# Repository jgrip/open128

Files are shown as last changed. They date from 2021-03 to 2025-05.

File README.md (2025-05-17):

## Migrated to codeberg <https://codeberg.org/jgrip/Open128>

View this project on [CADLAB.io](https://cadlab.io/project/24751). 

# open128

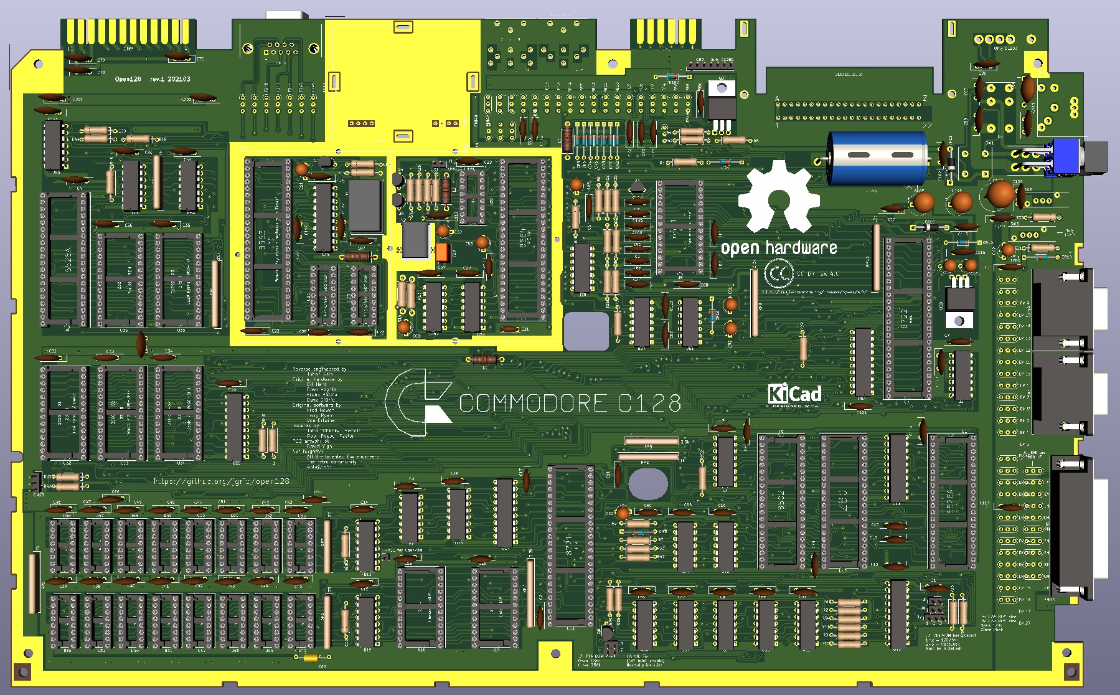
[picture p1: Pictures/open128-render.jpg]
Render of PCB


This is a clone of the Commodore 128 home computer made with KiCad, licensed under [CC BY-SA 4.0](https://creativecommons.org/licenses/by-sa/4.0/).

It contains both schematic and PCB layout, based on the Neo128 project by me.
This PCB has not yet been manufactured and tested however there are minimal changes compared to the well tested Neo128.

Some of the components have been copied from the [bit-preserve project](https://github.com/baldengineer/bit-preserve) and modified.

For Bill of Material and other documentation, please see https://c128.se

-----
This work is licensed under a
[Creative Commons Attribution-ShareAlike 4.0 International License][cc-by-sa].

[][cc-by-sa]

[cc-by-sa]: http://creativecommons.org/licenses/by-sa/4.0/
[cc-by-sa-image]: https://licensebuttons.net/l/by-sa/4.0/88x31.png
[cc-by-sa-shield]: https://img.shields.io/badge/License-CC%20BY--SA%204.0-lightgrey.svg

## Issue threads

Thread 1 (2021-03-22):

Silkscreen issues

jgrip, 2021-03-22:
The silk screen is a bit messed up and needs to be fixed.

Component values, most of the EMI references etc.

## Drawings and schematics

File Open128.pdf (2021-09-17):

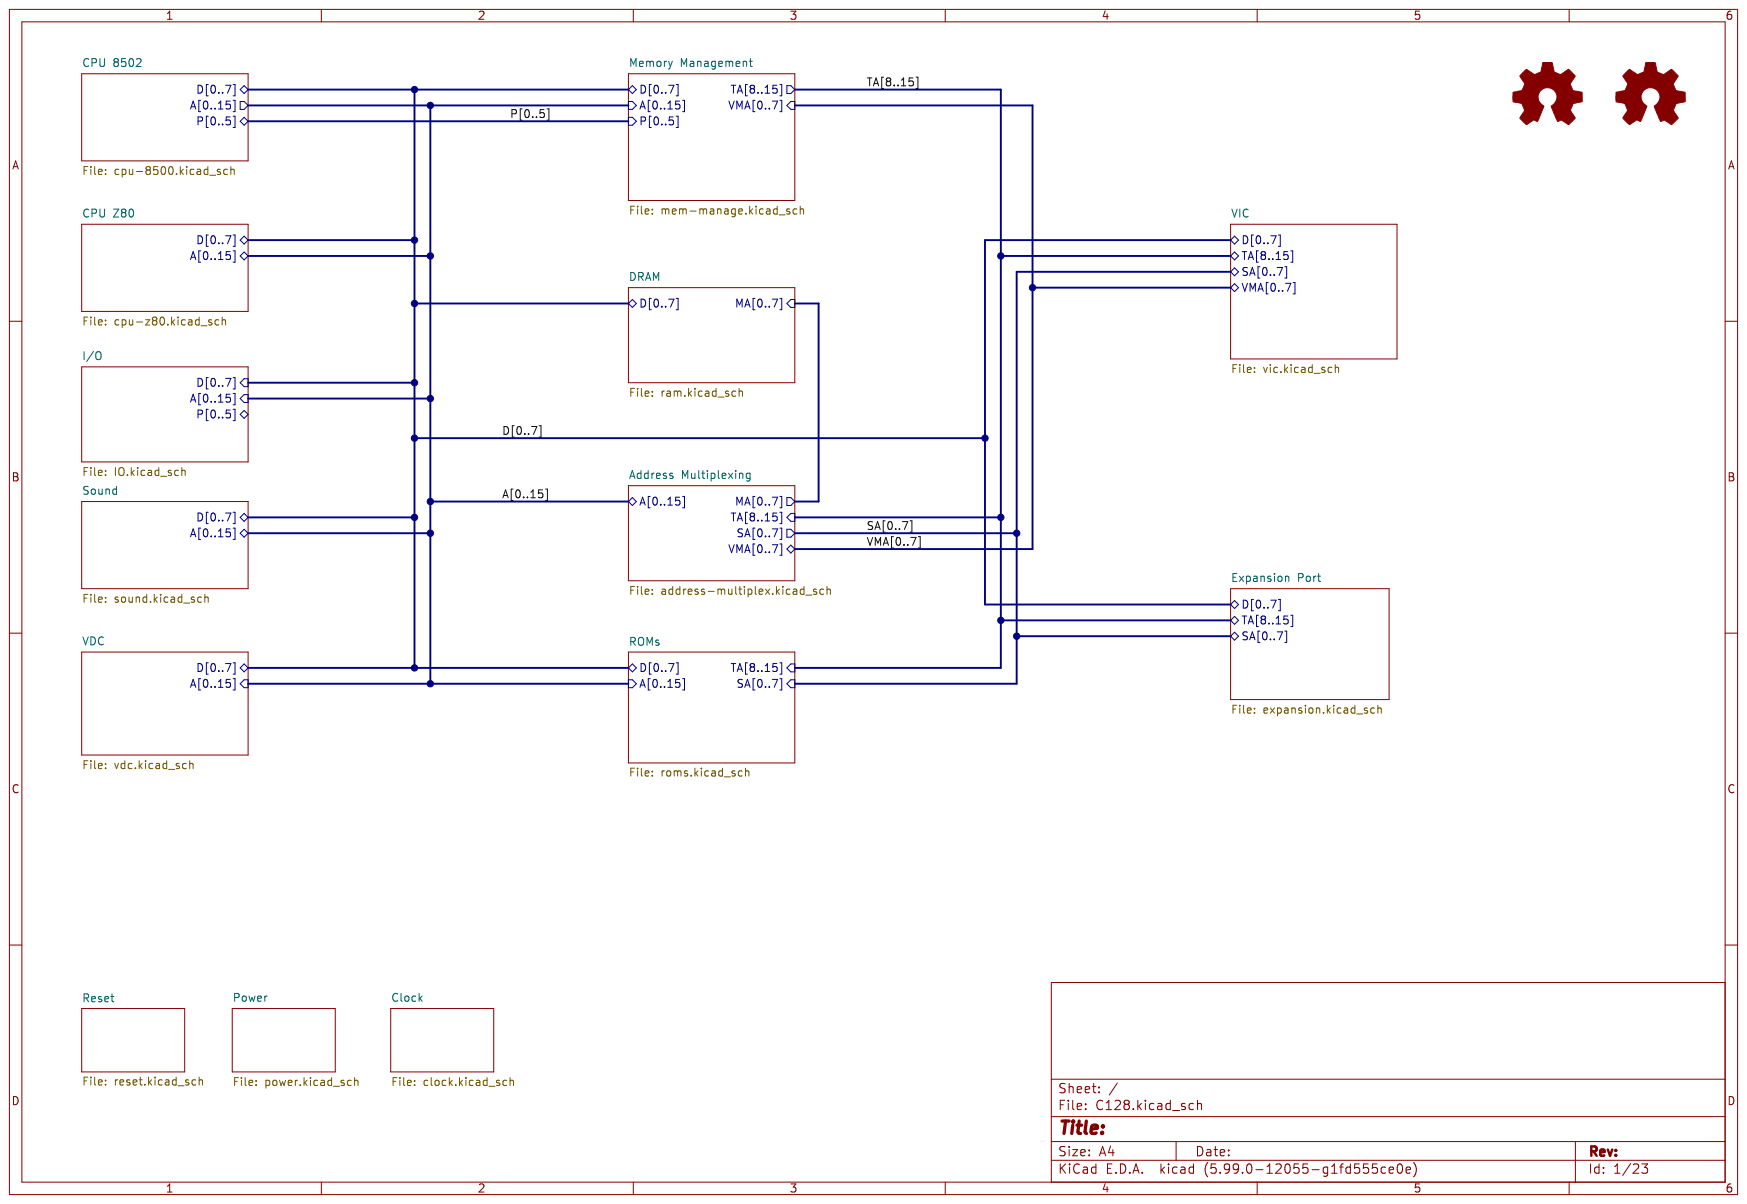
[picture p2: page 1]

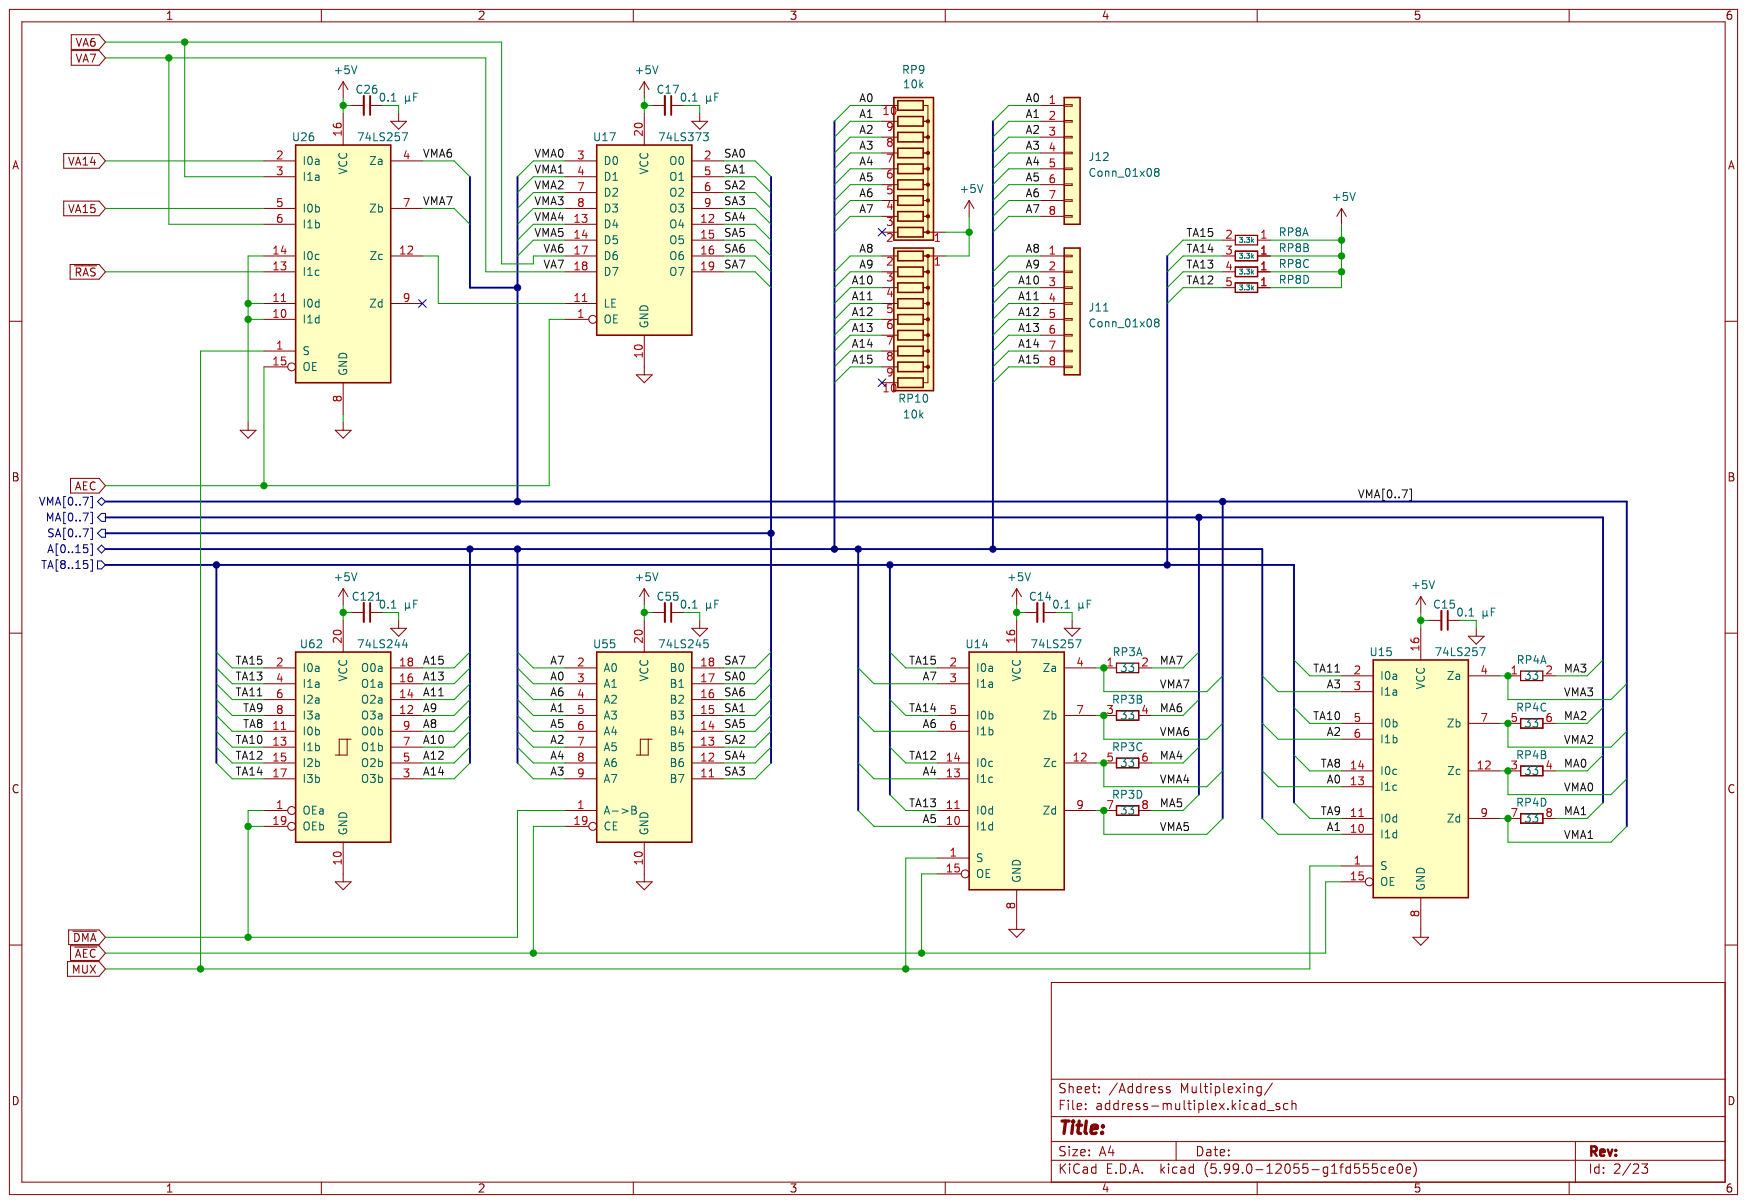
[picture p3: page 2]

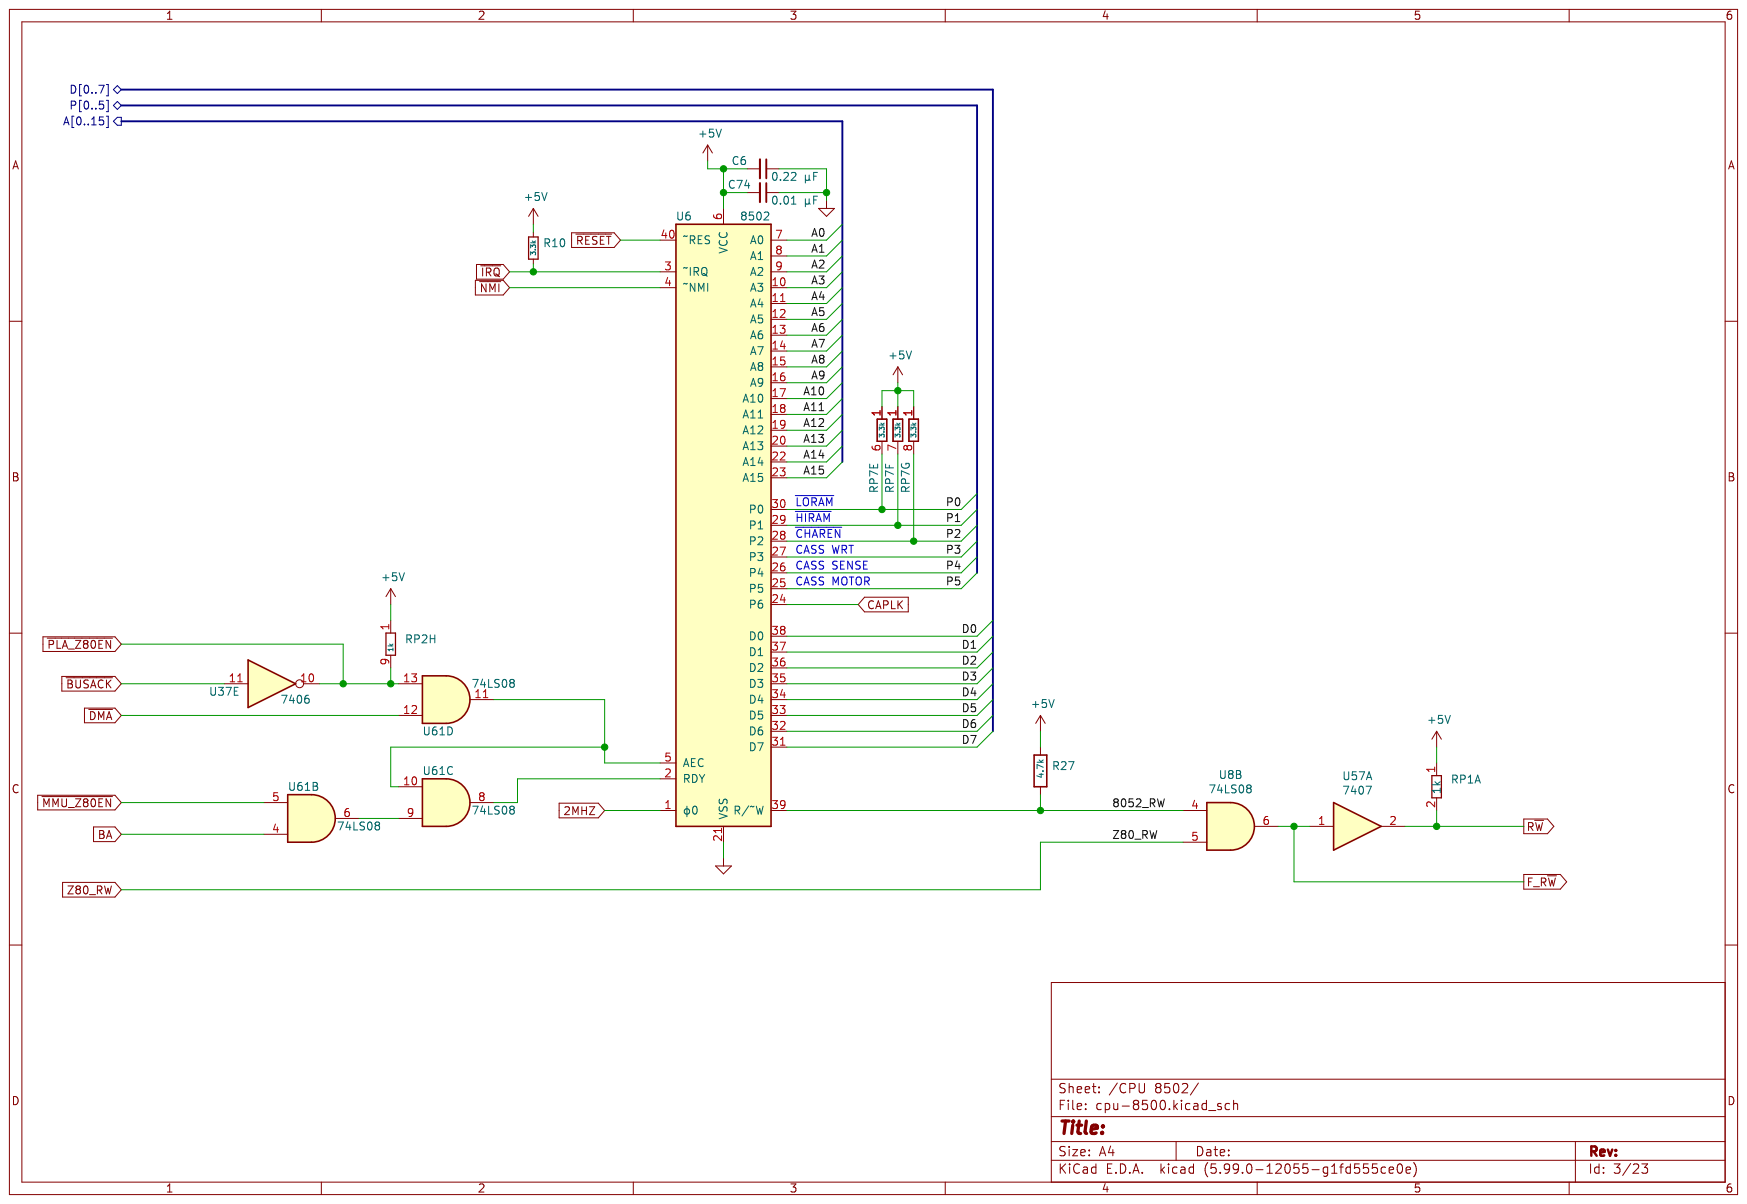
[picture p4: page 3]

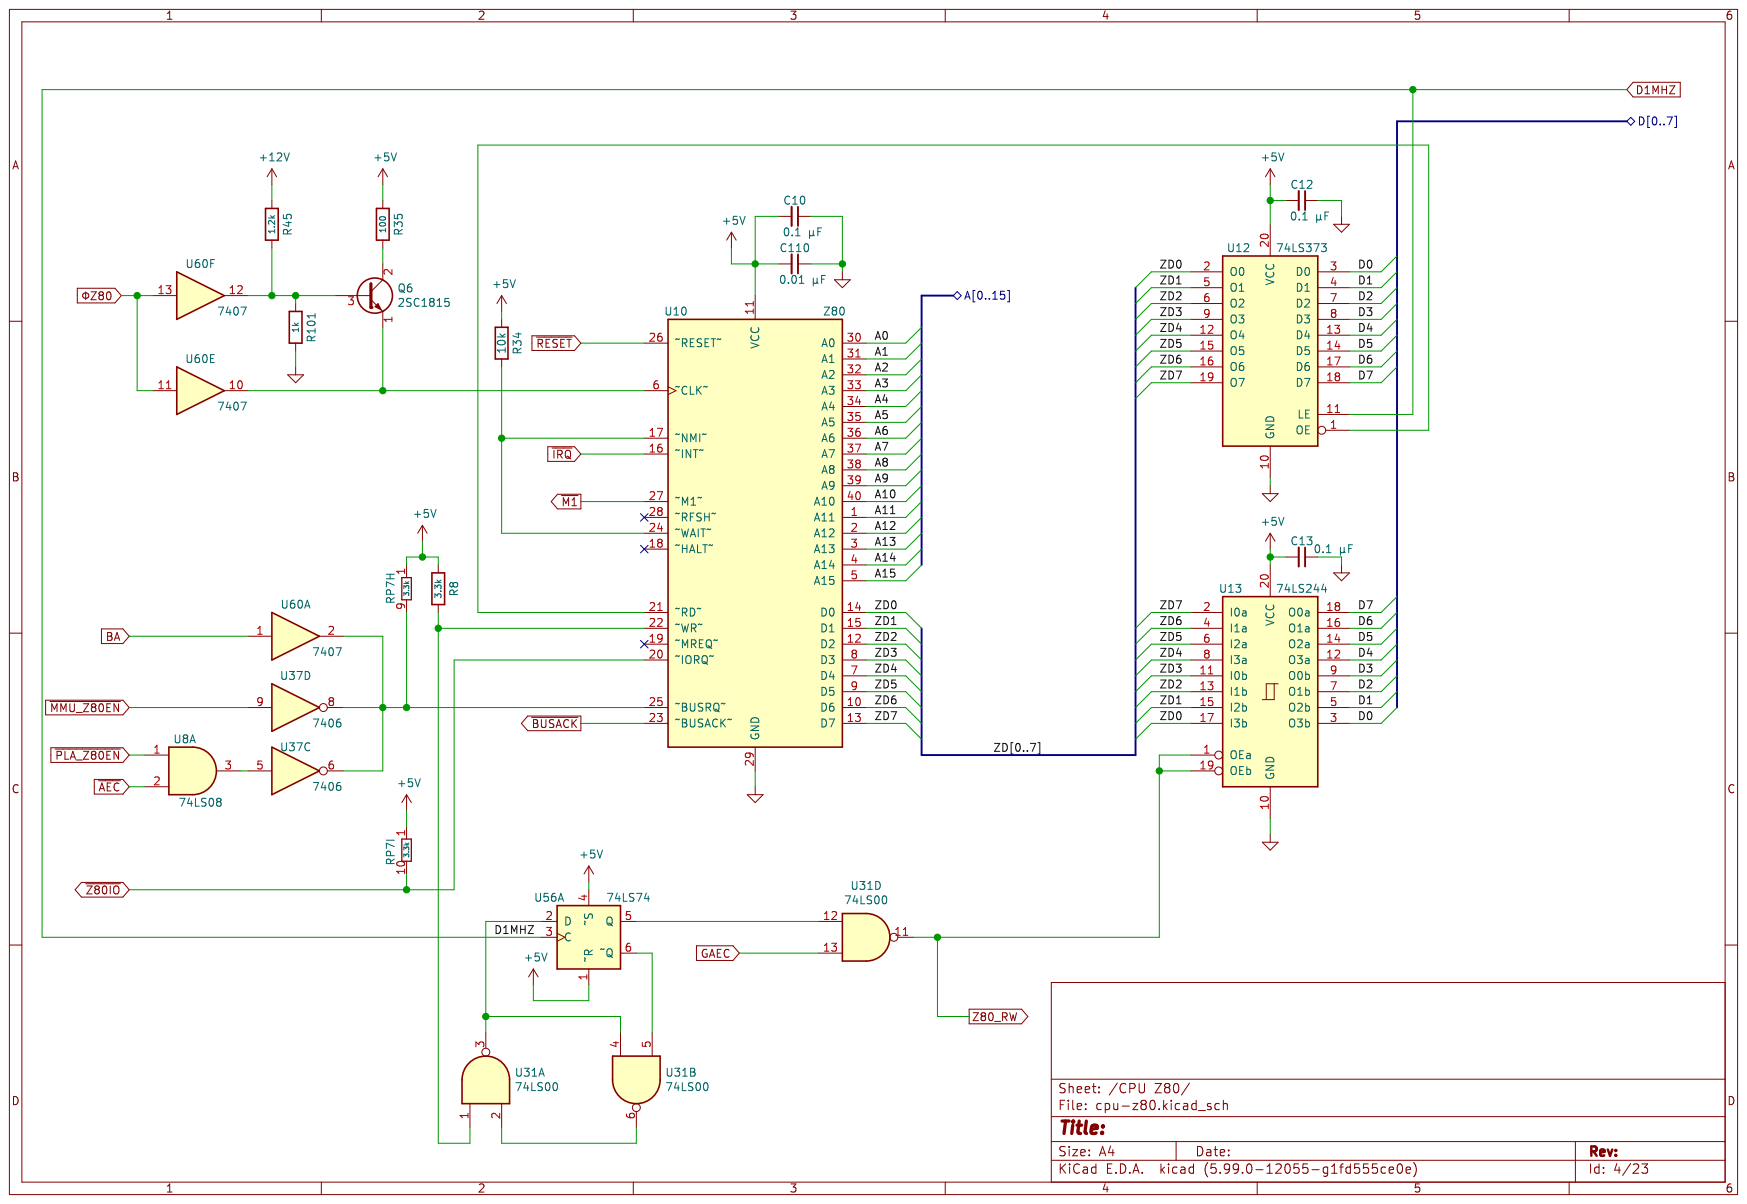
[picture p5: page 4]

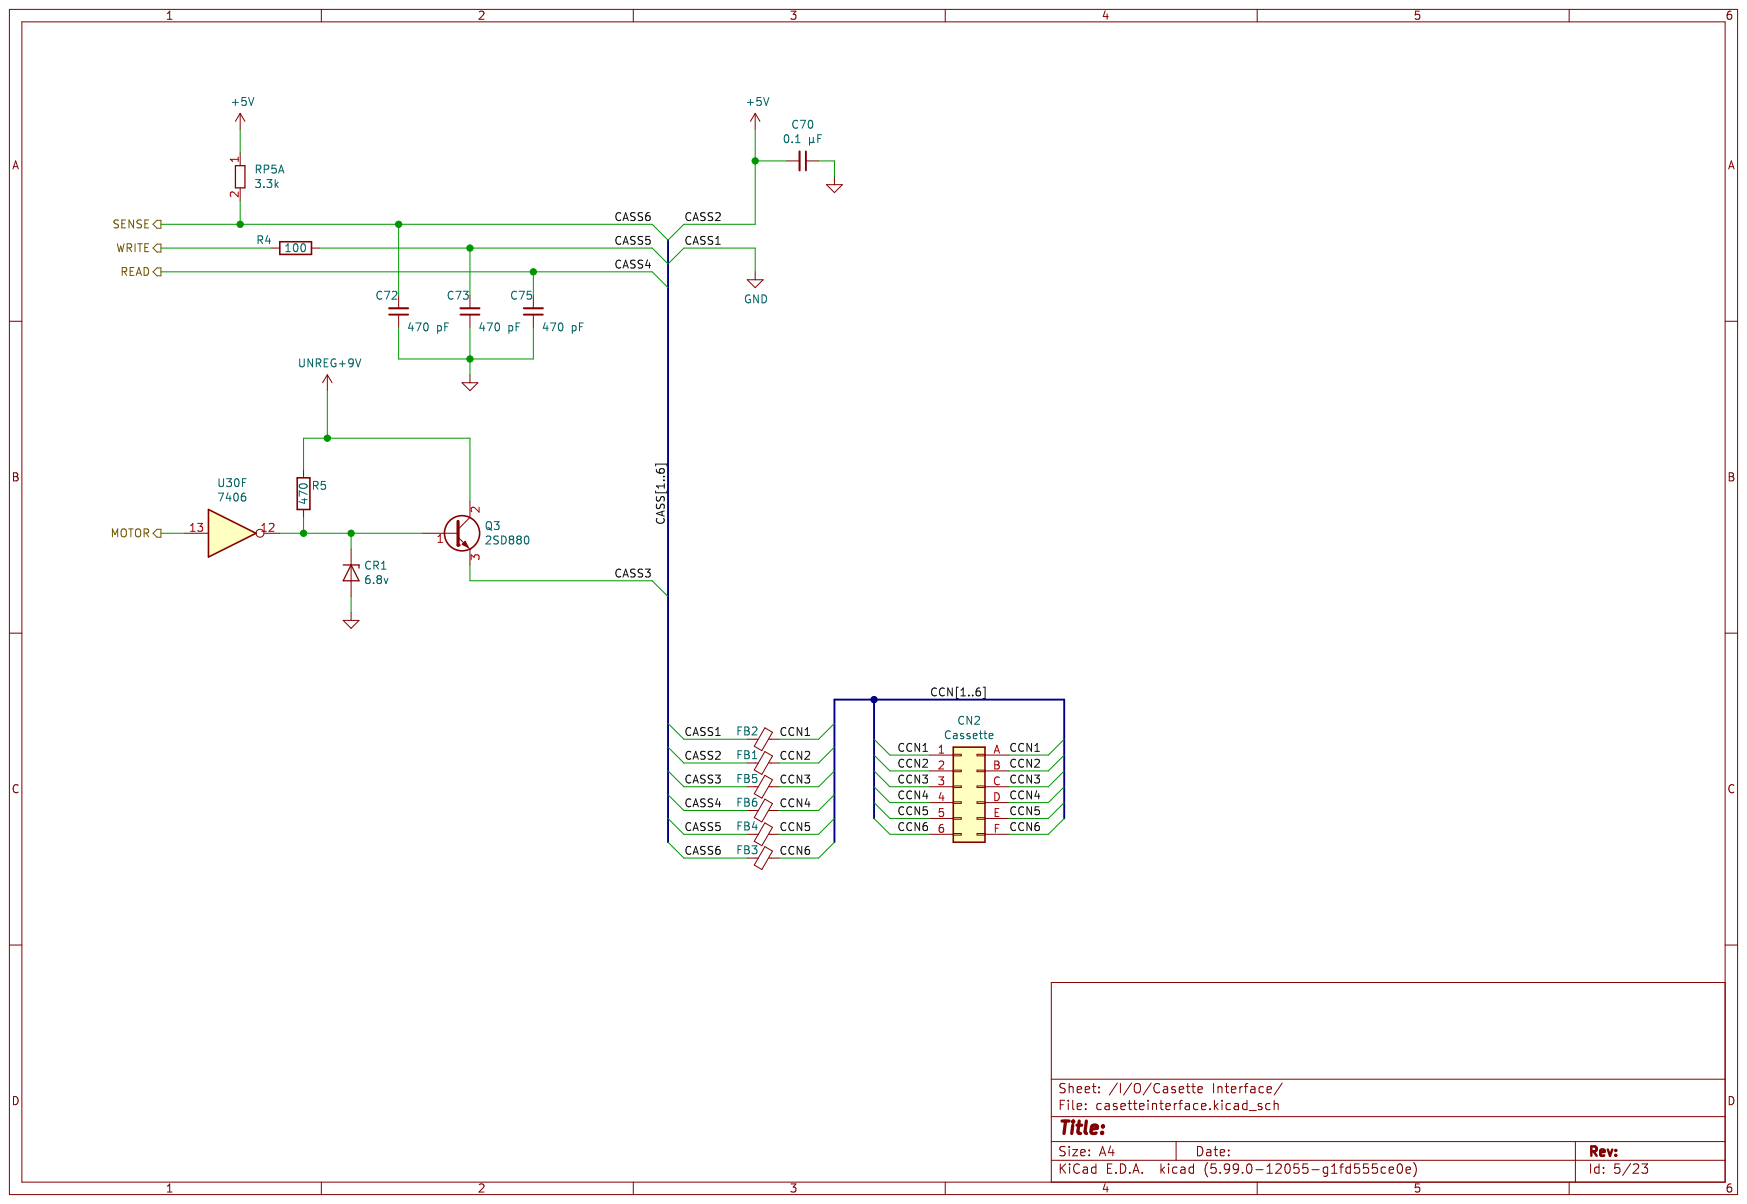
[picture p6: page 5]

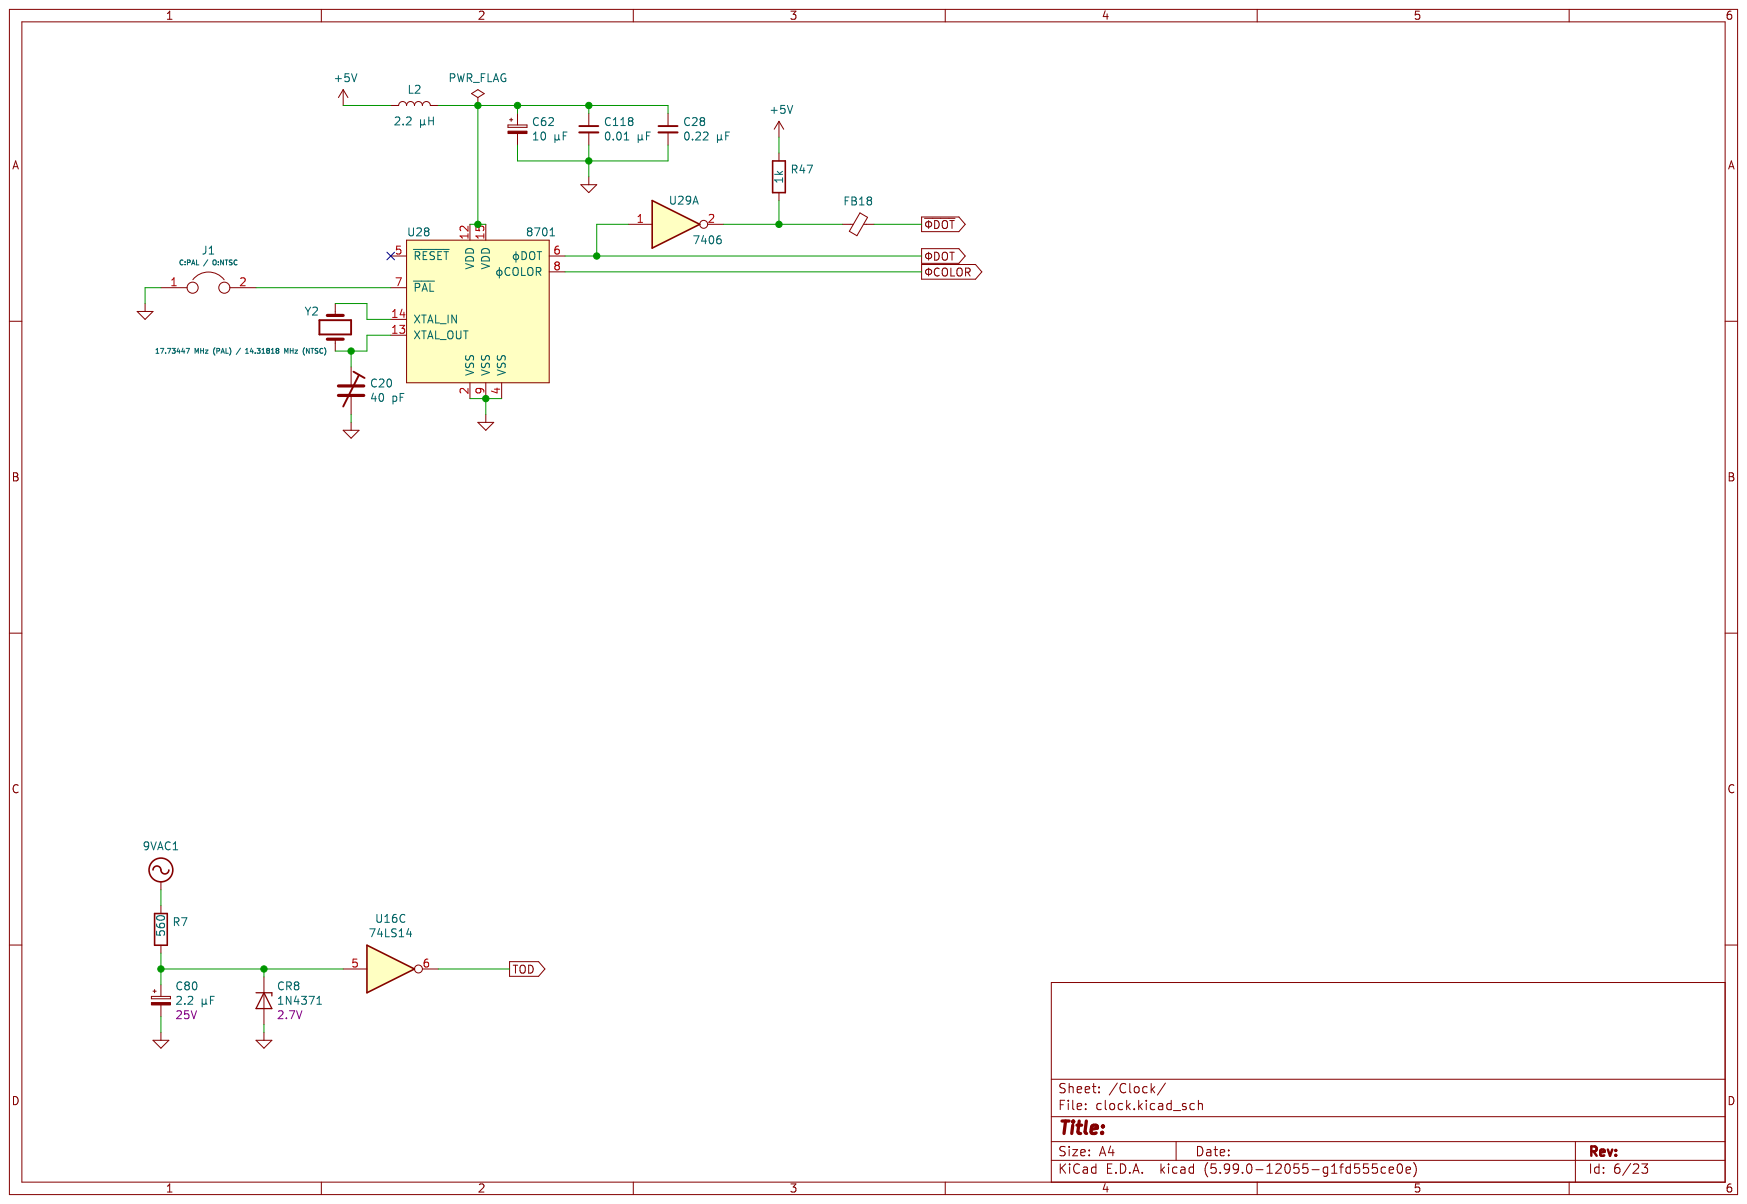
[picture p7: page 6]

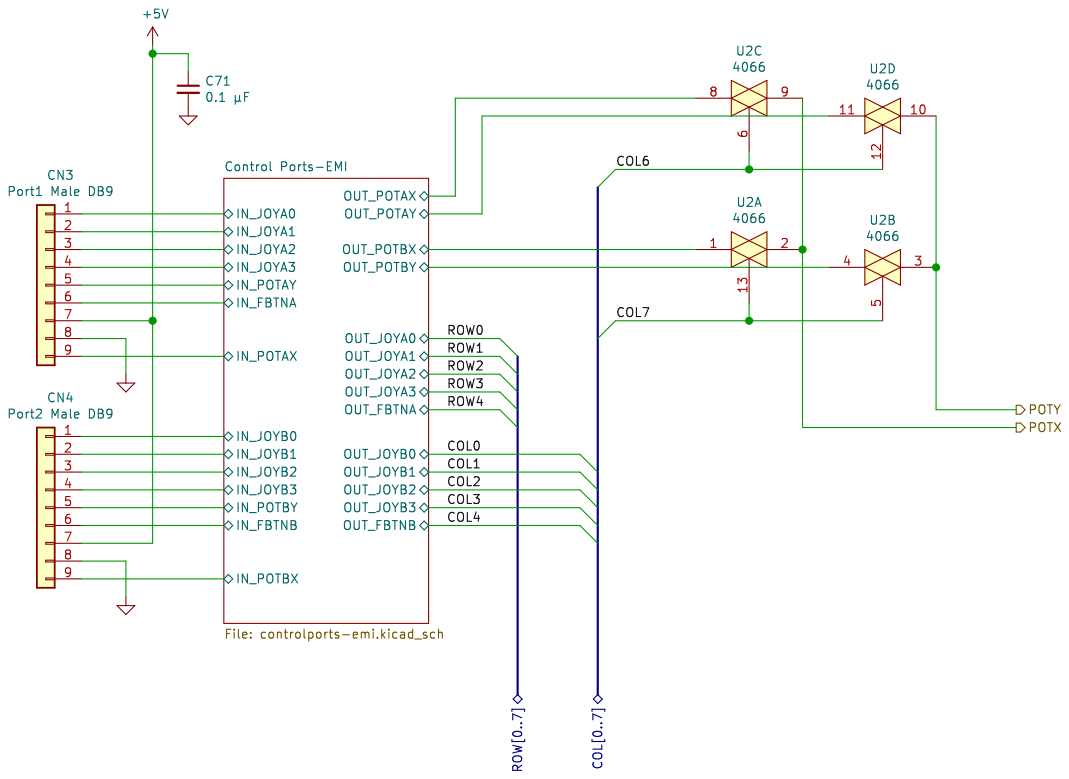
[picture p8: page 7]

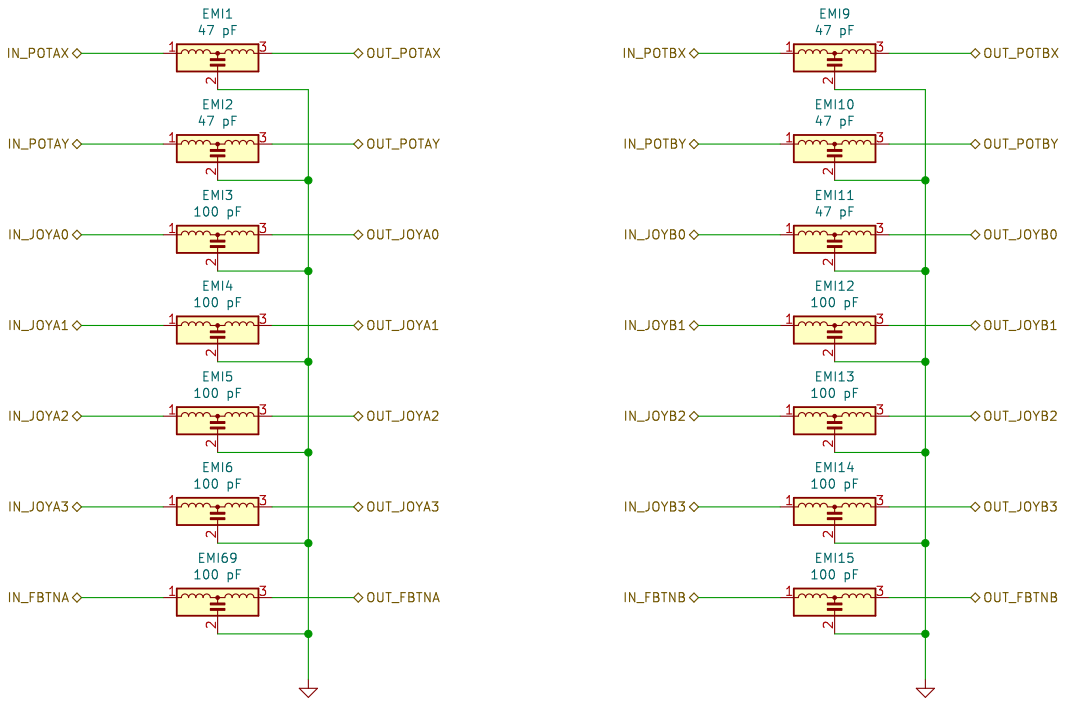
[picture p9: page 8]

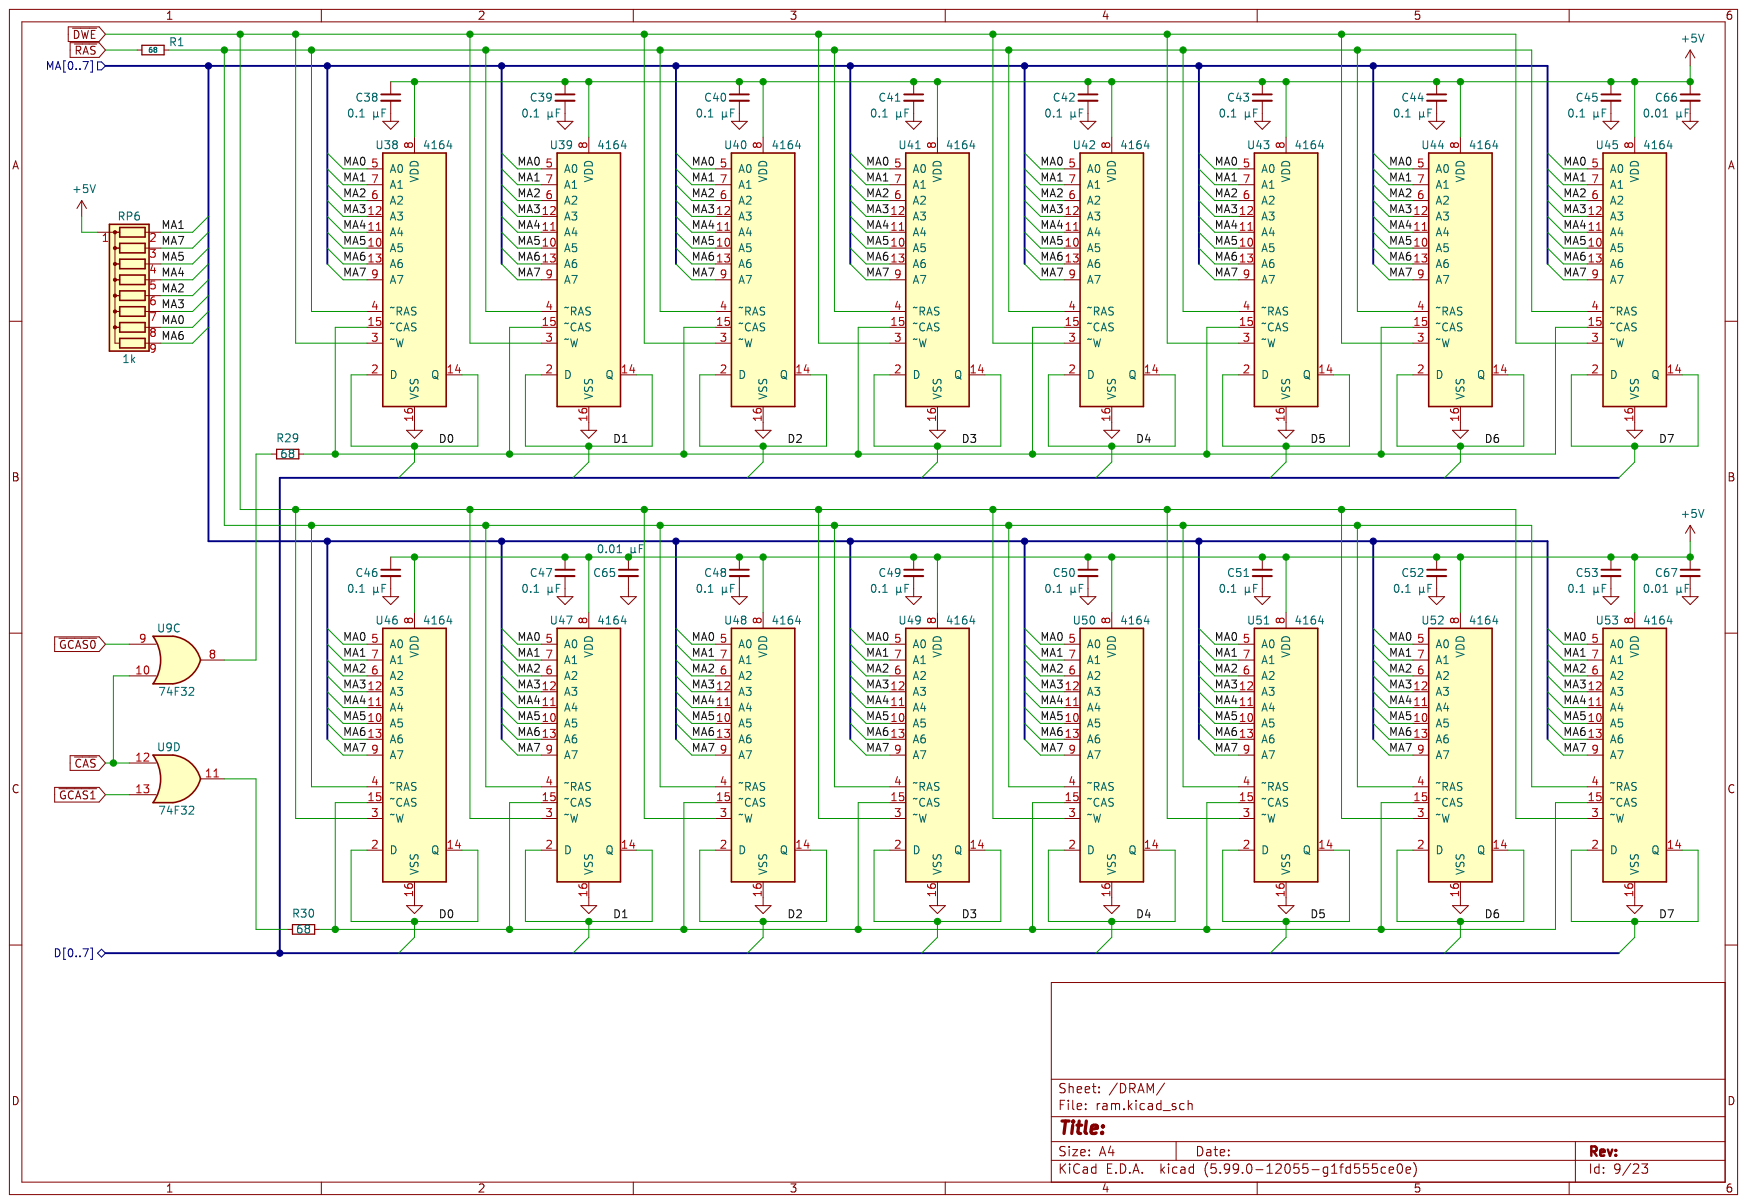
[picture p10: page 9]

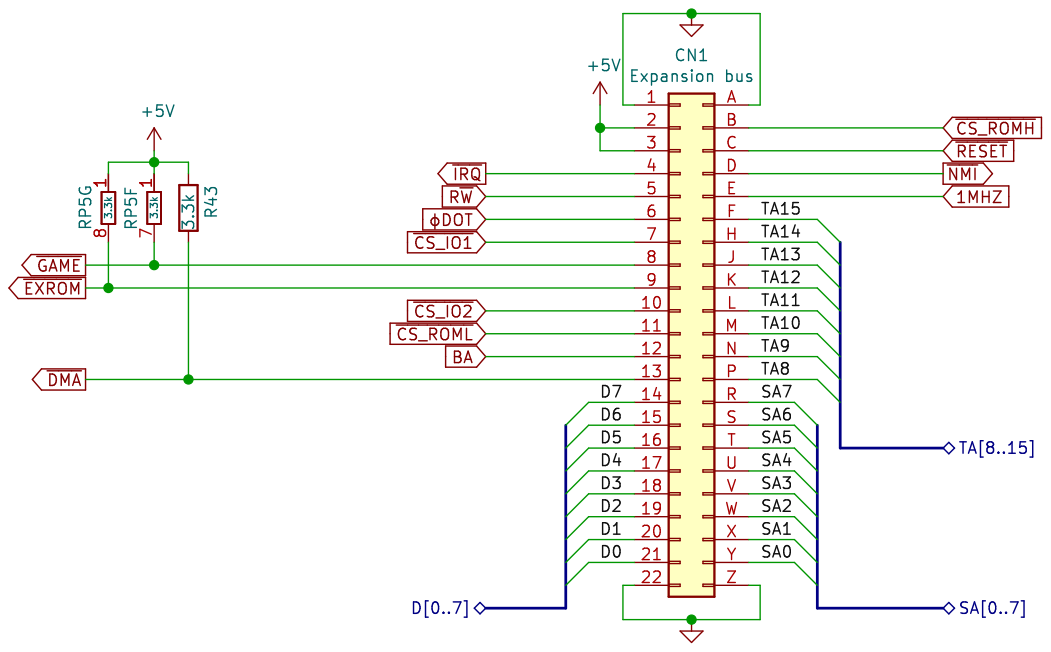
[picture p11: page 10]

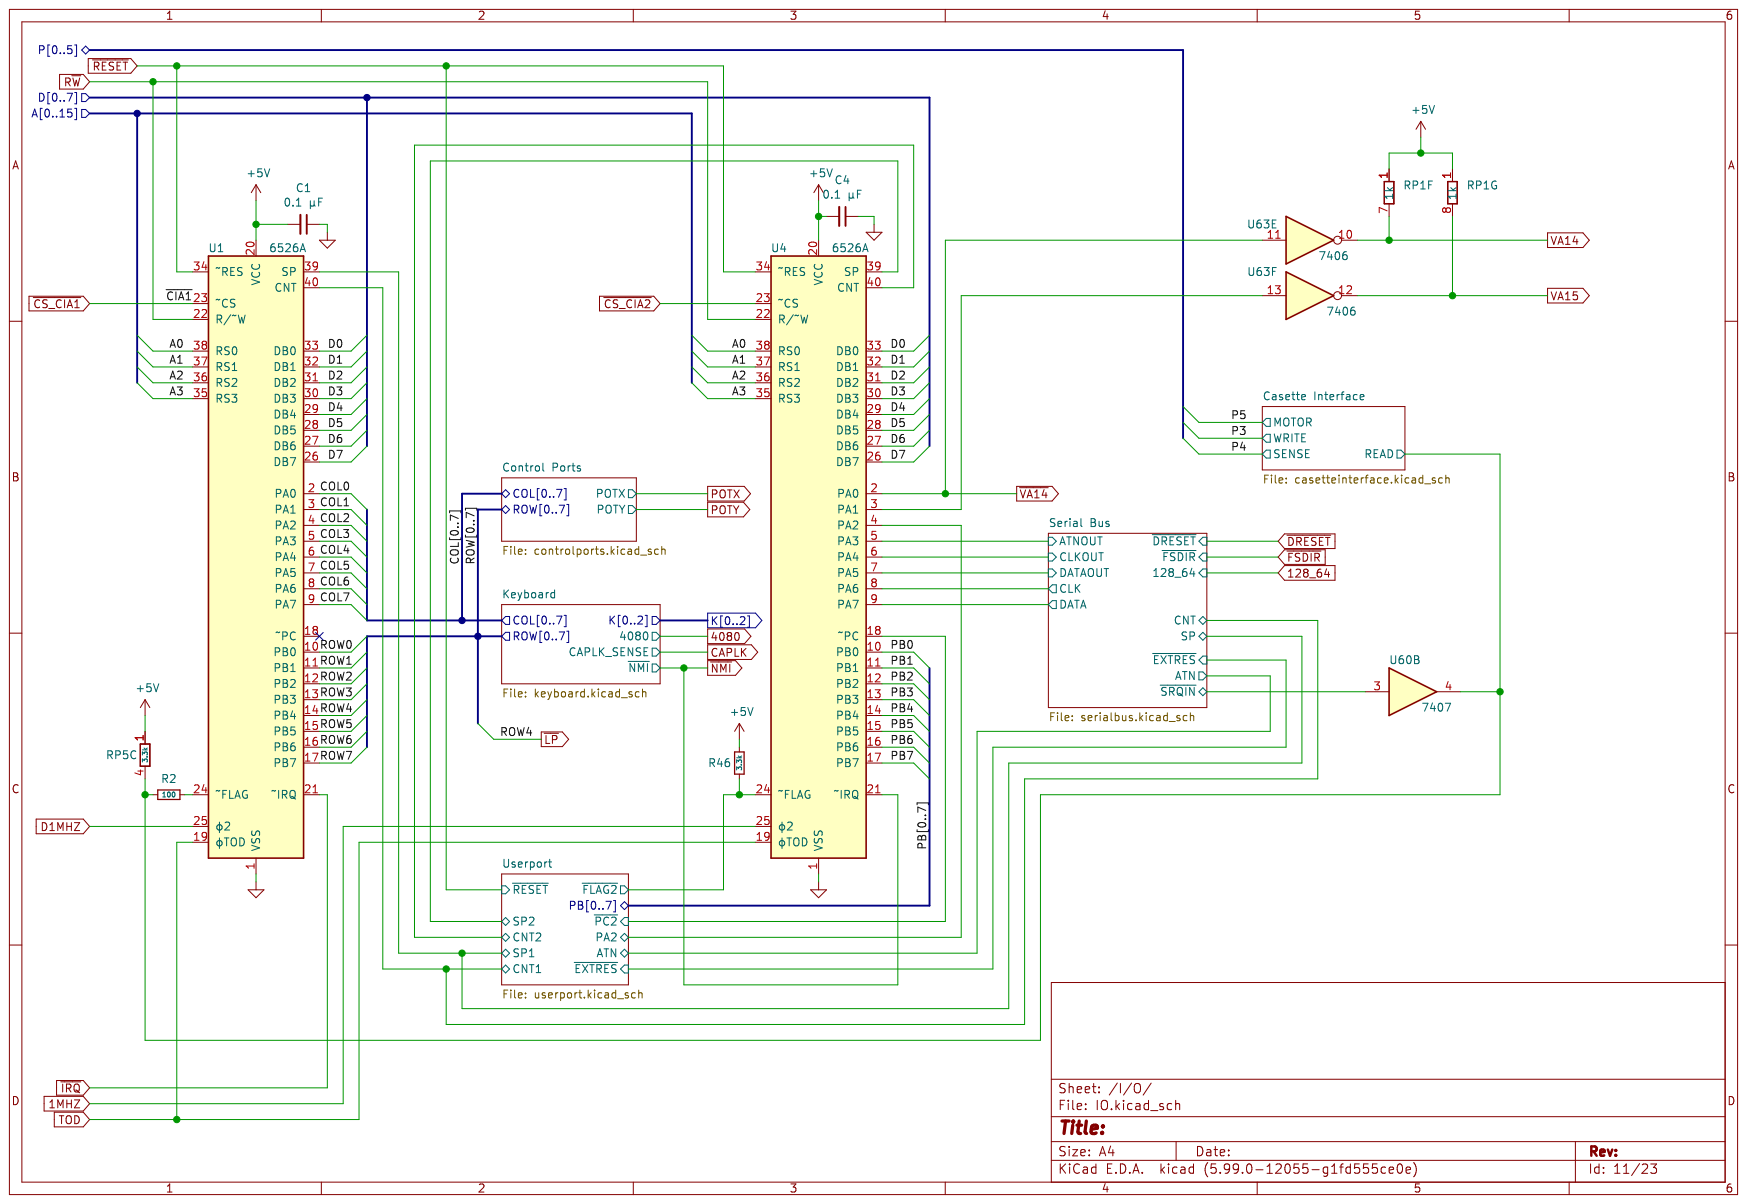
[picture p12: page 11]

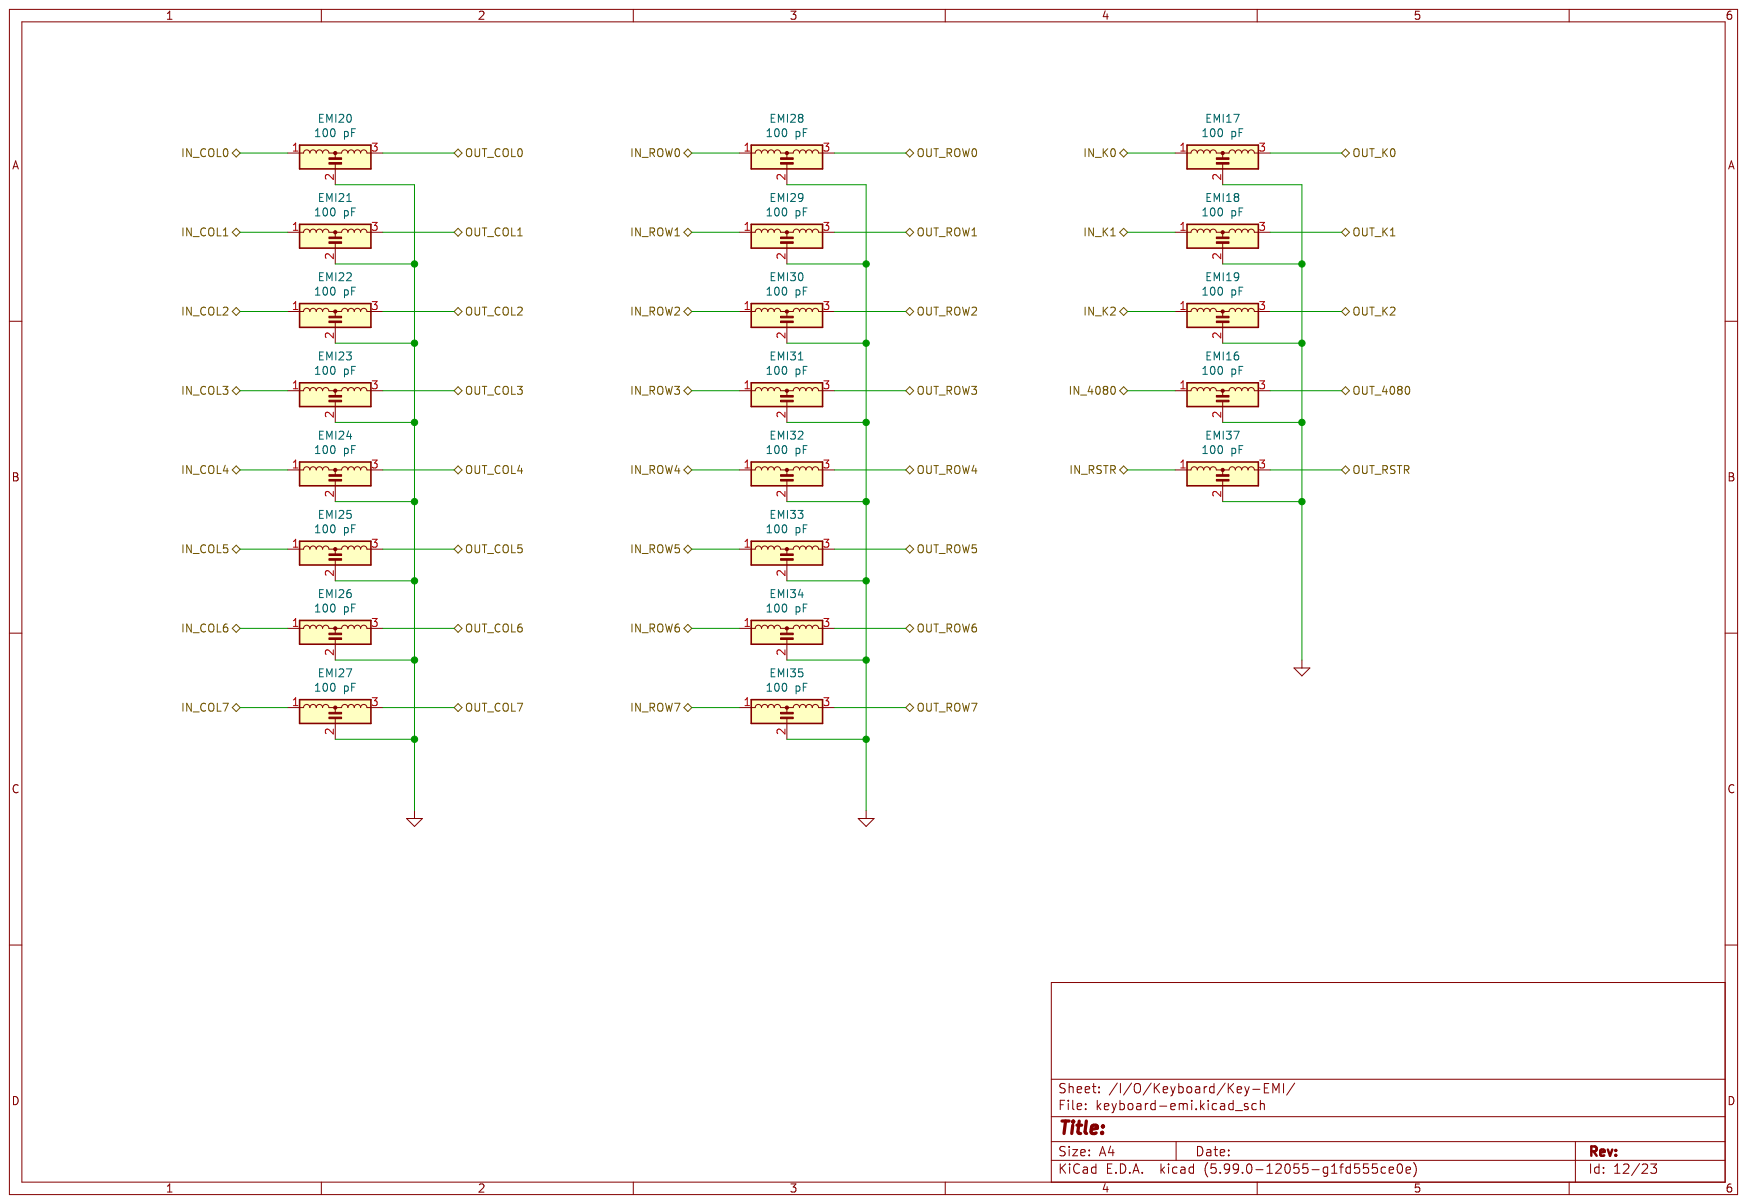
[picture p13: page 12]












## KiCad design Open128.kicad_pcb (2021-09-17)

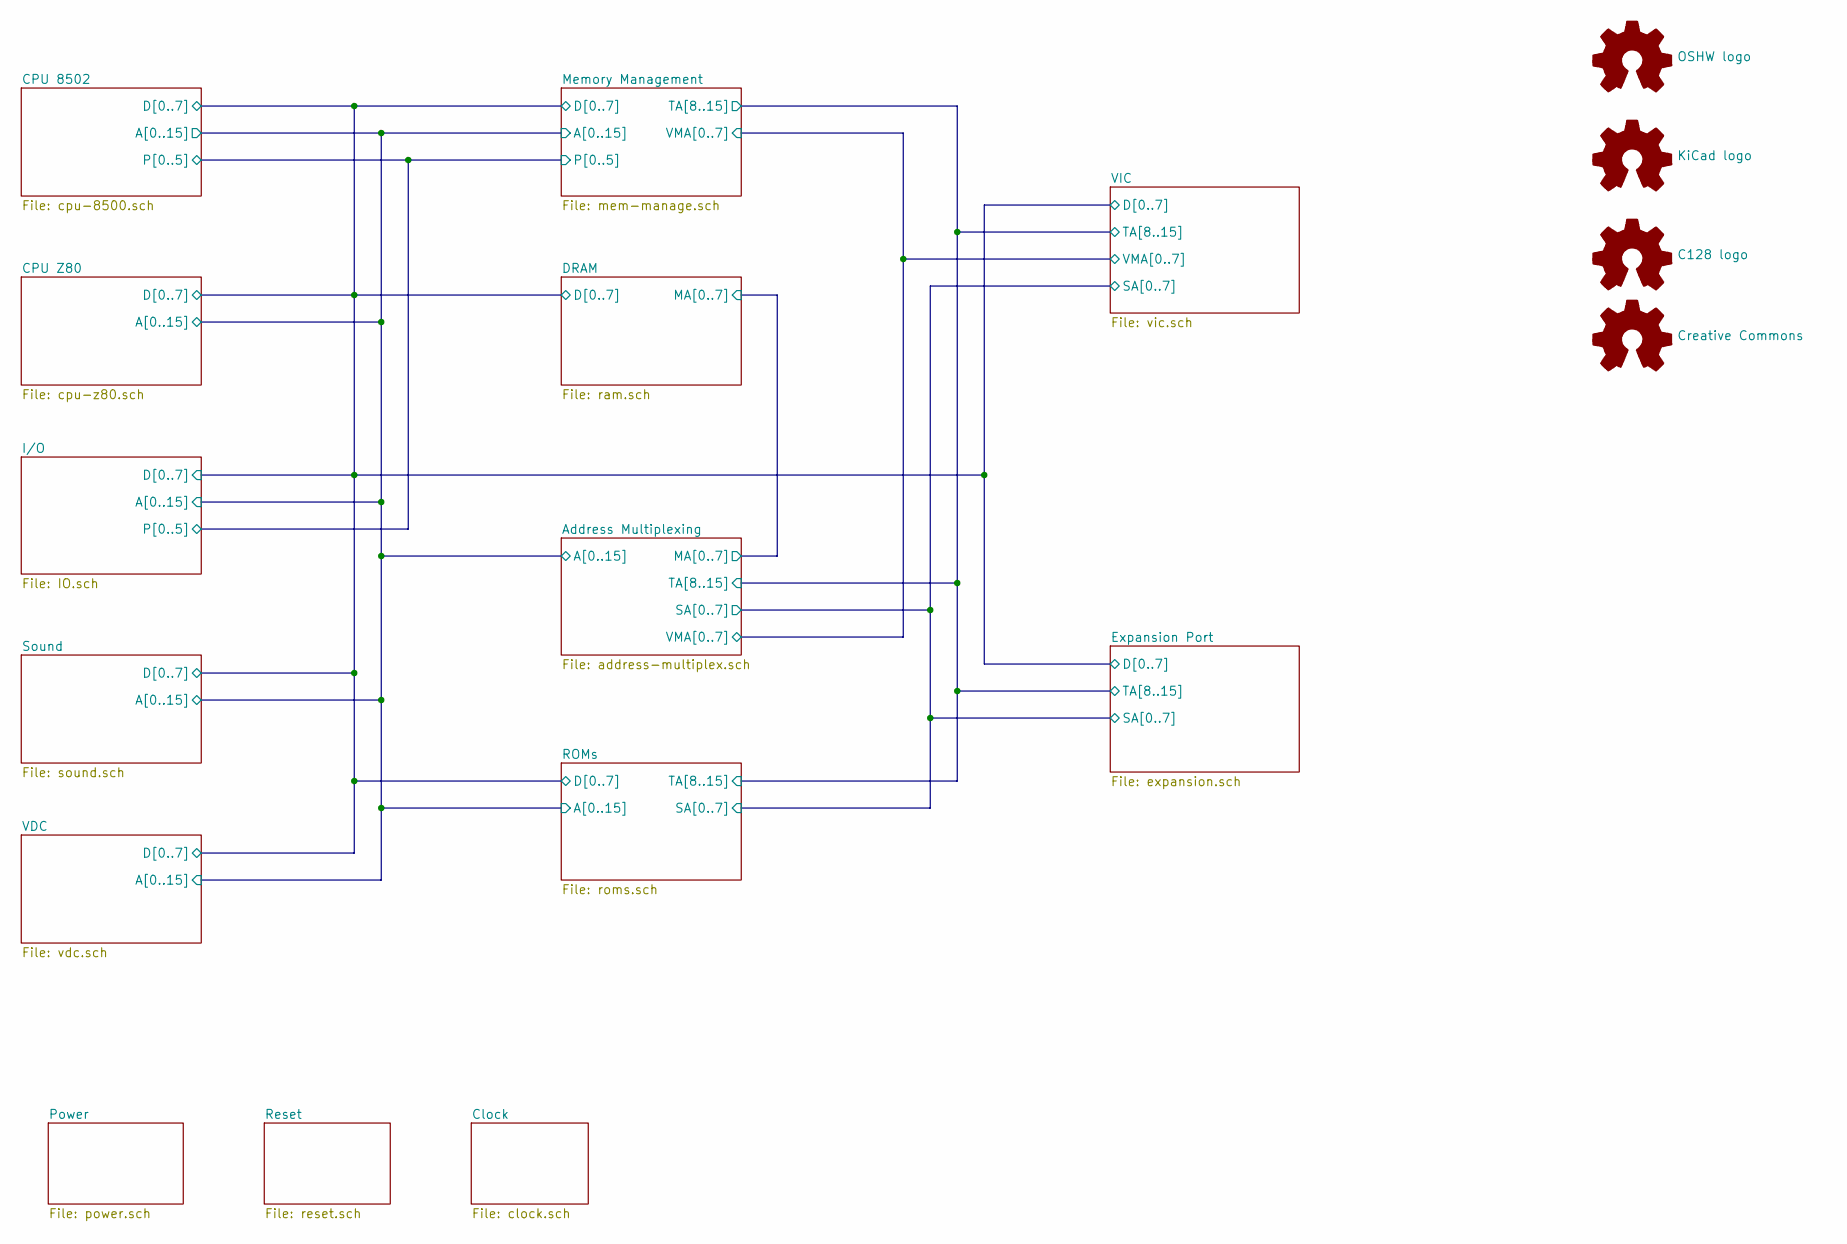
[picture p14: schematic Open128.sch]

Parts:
LOGO1: OSHW logo; OSHW-Logo2_48.7x40mm_SilkScreen
LOGO2: KiCad logo; KiCad-Logo2_8mm_SilkScreen
LOGO3: C128 logo; C128-logo
LOGO4: Creative Commons; Symbol_CreativeCommons_SilkScreenTop_Type2_Big

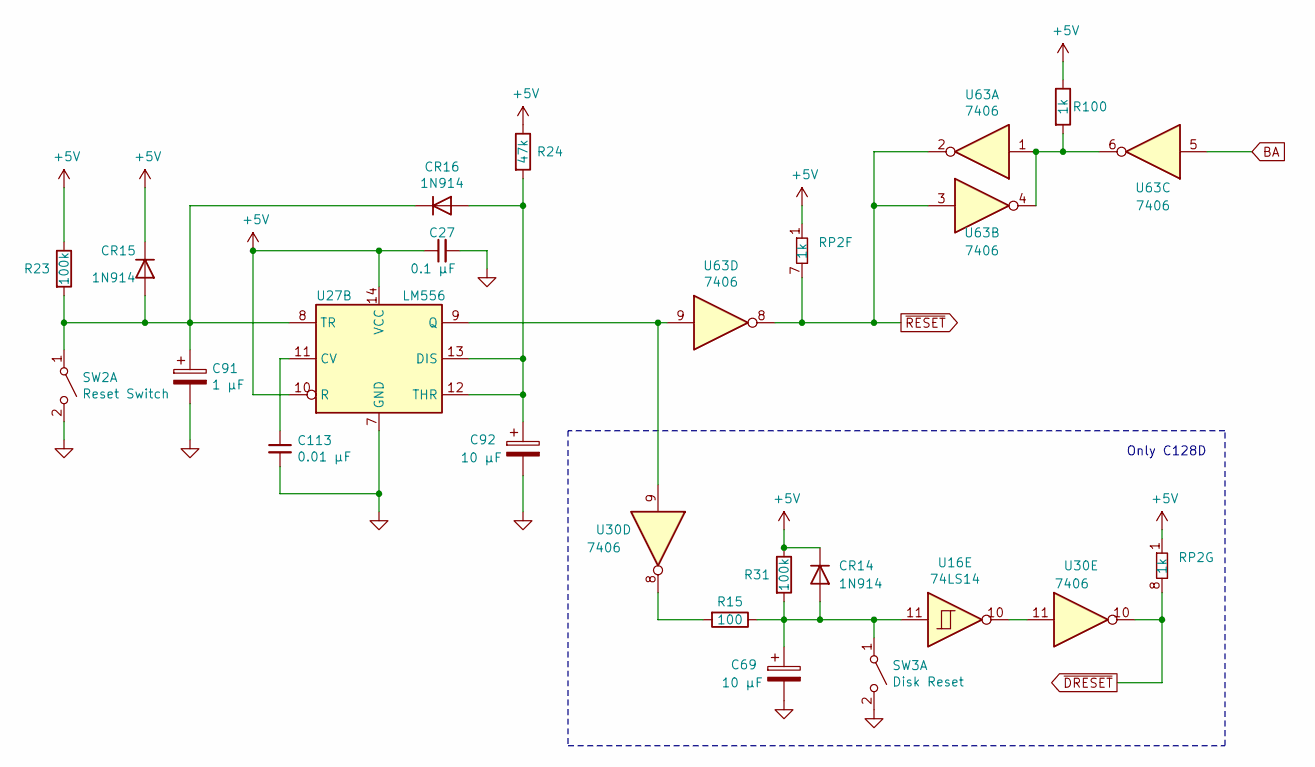
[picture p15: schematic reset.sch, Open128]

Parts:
C27: 0.1 µF; C_Disc_D10.0mm_W2.5mm_P5.00mm; Voltage Rating 25V; Voltage Tolerance +80% -20%; Mouser Part 581-SA105E104MAR
C69, C92: 10 µF; CP_Radial_Tantal_D5.0mm_P5.00mm; Voltage Rating 16V; Mouser Part 647-UVR1H100MDD1TD
C91: 1 µF; CP_Radial_Tantal_D5.0mm_P5.00mm; Voltage Rating 16V; Mouser Part 647-USA1H010MDD1TE
C113: 0.01 µF; C_Disc_D10.0mm_W2.5mm_P5.00mm; Voltage Rating 25V; Voltage Tolerance +80% -20%; Mouser Part 581-SA105E103M
CR14, CR15, CR16: 1N914; D_DO-35_SOD27_P12.70mm_Horizontal; Mouser Part 512-1N914
R15: 100; R_Axial_DIN0309_L9.0mm_D2.5mm_P12.70mm_Horizontal; Mouser Part 660-MF1/4DCT52A1000F
R23, R31: 100k; R_Axial_DIN0309_L9.0mm_D2.5mm_P12.70mm_Horizontal; Mouser Part 660-MF1/4LCT52R104J
R24: 47k; R_Axial_DIN0309_L9.0mm_D2.5mm_P12.70mm_Horizontal; Mouser Part 660-MF1/4LCT52R473J
R100: 1k; R_Axial_DIN0309_L9.0mm_D2.5mm_P12.70mm_Horizontal; Mouser Part 660-MF1/4LCT52R102J
RP2: 1k; R_Array_SIP9; Mouser Part 652-4609X-1LF-1K
SW2: Reset Switch; Switch-Pushbutton
SW3: Disk Reset; Switch-Pushbutton
U16: 74LS14; DIP-14_W7.62mm; Mouser Part 595-SN74LS14N
U27: LM556; DIP-14_W7.62mm; Mouser Part 595-NA556N
U30, U63: 7406; DIP-14_W7.62mm; Mouser Part 595-SN74LS06N

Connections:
+5V: C27.1, CR14.1 (K), CR15.1 (K), R23.1, R24.1, R31.1, R100.1, RP2.1 (common), U27.10 (R), U27.14 (VCC); also elsewhere on the board
BA: U63.5; also elsewhere on the board
GND: C27.2, C69.2, C91.2, C92.2, C113.2, SW2.2 (B), SW3.2 (B), U27.7 (GND); also elsewhere on the board
unnamed: C69.1, CR14.2 (A), R15.1, R31.2, SW3.1 (A), U16.11
unnamed: C91.1, CR15.2 (A), CR16.1 (K), R23.2, SW2.1 (A), U27.8 (TR)
unnamed: C92.1, CR16.2 (A), R24.2, U27.12 (THR), U27.13 (DIS)
unnamed: C113.1, U27.11 (CV)
unnamed: R15.2, U30.8
unnamed: R100.2, U63.1, U63.4, U63.6
unnamed: U16.10, U30.11
unnamed: U27.9 (Q), U30.9, U63.9
~DRESET: RP2.8 (R8), U30.10; also elsewhere on the board
~RESET: RP2.7 (R8), U63.2, U63.3, U63.8; also elsewhere on the board

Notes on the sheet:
Only C128D

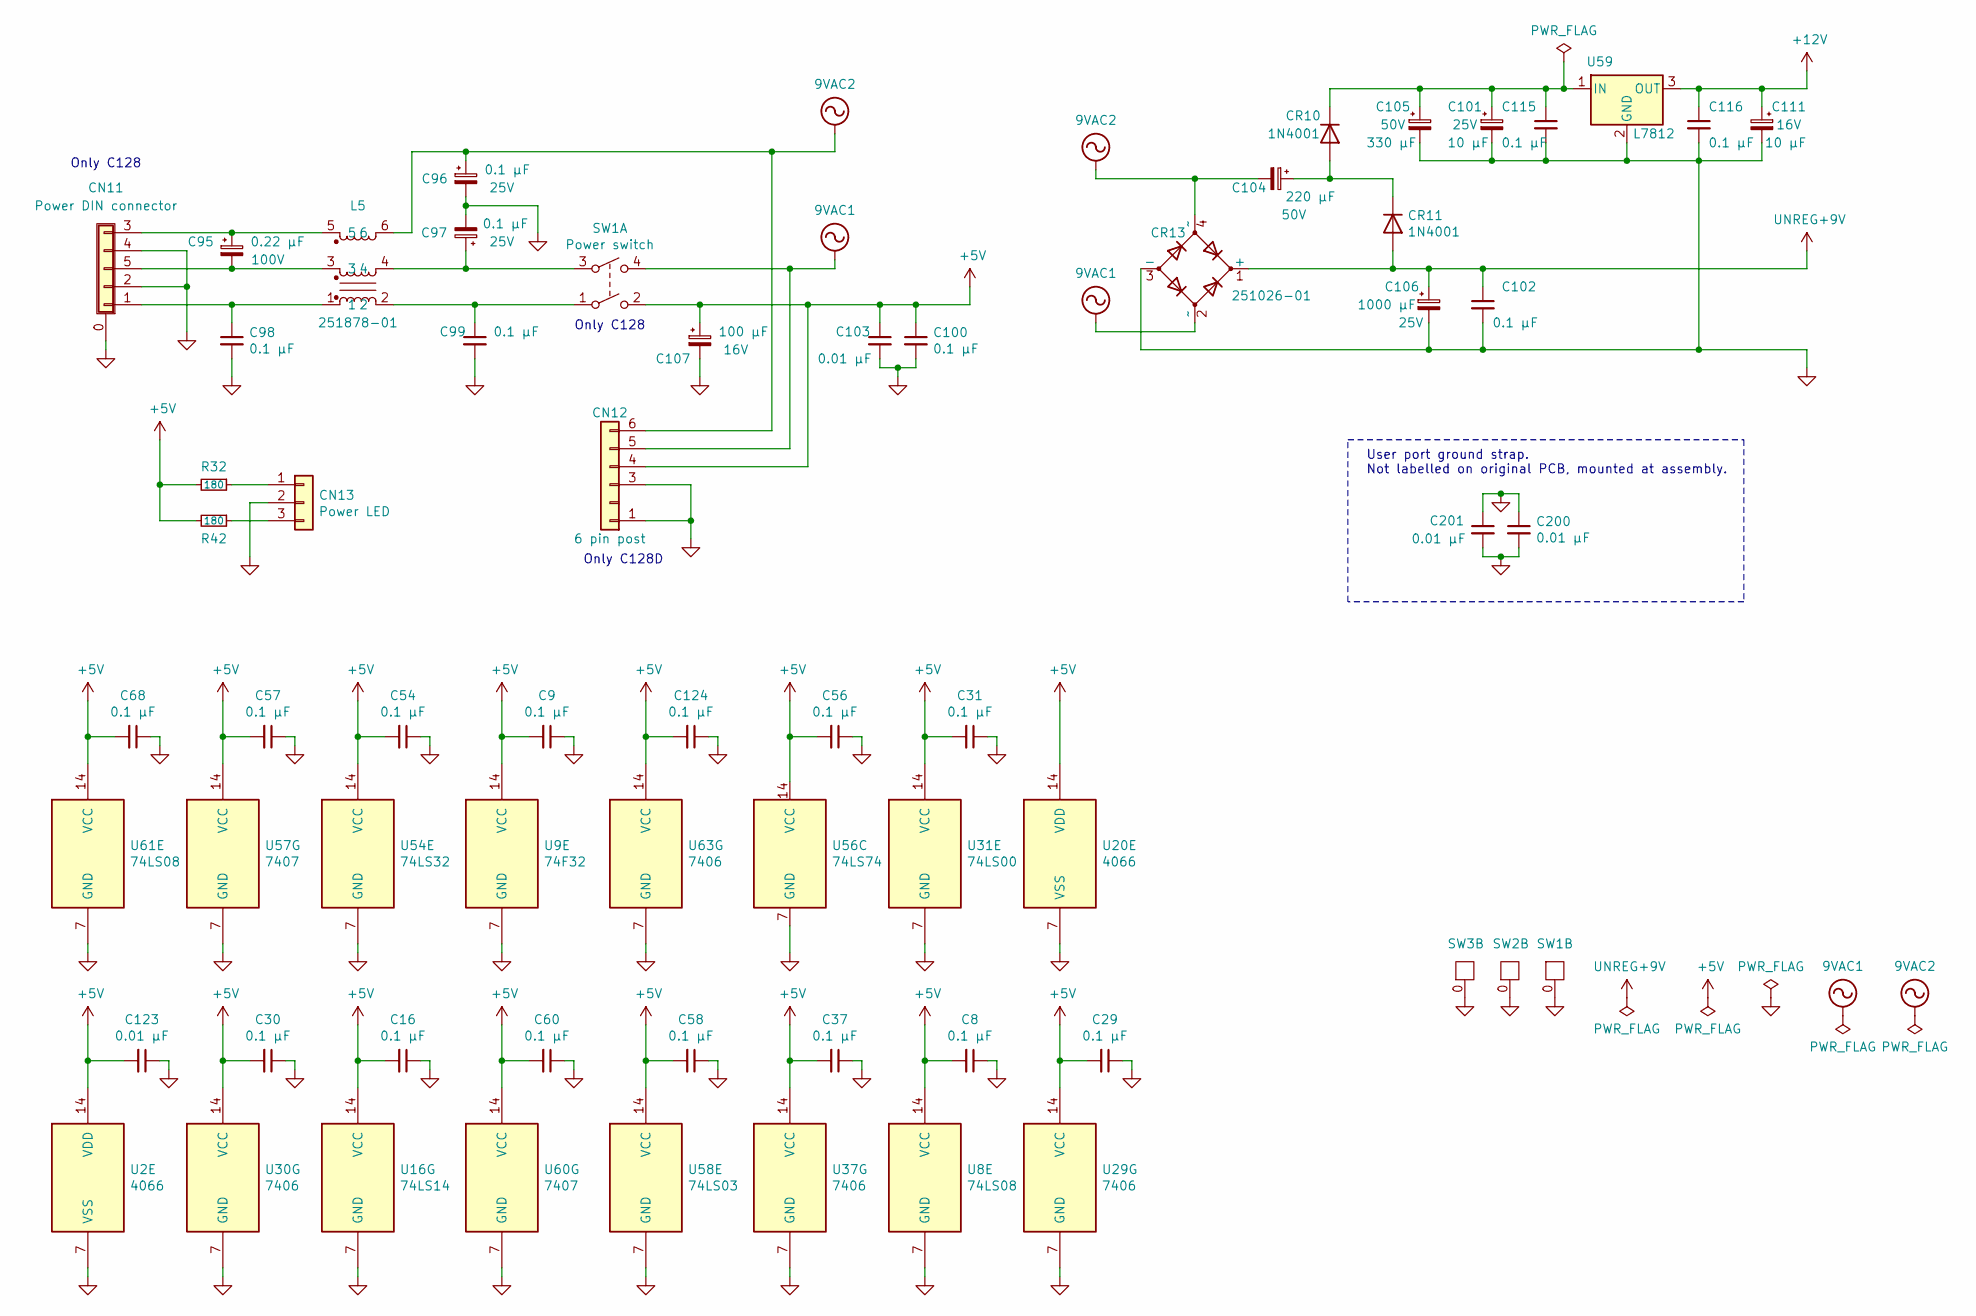
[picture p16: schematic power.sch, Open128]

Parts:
C8, C9, C16, C29, C30, C31, C37, C54, C56, C57, C58, C60, C68, C96, C97, C98, C99, C100, C102, C115, C116, C124: 0.1 µF; C_Disc_D10.0mm_W2.5mm_P5.00mm; Voltage Rating 25V; Voltage Tolerance +80% -20%; Mouser Part 581-SA105E104MAR
C95: 0.22 µF; C_Disc_D10.5mm_W5.0mm_P10.00mm; Voltage Rating 100V; Voltage Tolerance +80% -20%; Mouser Part 581-SA115E224MAR
C101: 10 µF; CP_Radial_Tantal_D5.0mm_P5.00mm; Voltage Rating 25V; Voltage Tolerance +80% -20%; Mouser Part 647-UVR1H100MDD1TD
C103, C123, C200, C201: 0.01 µF; C_Disc_D10.0mm_W2.5mm_P5.00mm; Voltage Rating 25V; Voltage Tolerance +80% -20%; Mouser Part 581-SA105E103M
C104: 220 µF; CP_Radial_Tantal_D8.0mm_P5.00mm; Voltage Rating 50V; Voltage Tolerance +80% -20%; Mouser Part 647-UVZ1H221MPD1TD
C105: 330 µF; CP_Radial_Tantal_D8.0mm_P5.00mm; Voltage Rating 50V; Voltage Tolerance +80% -20%; Mouser Part 647-UVZ1H331MPD1TD
C106: 1000 µF; CP_Axial_L34.5mm_D20.0mm_P41.00mm_Horizontal; Voltage Rating 25V; Voltage Tolerance +80% -20%; Mouser Part 647-TVX1H102MCD
C107: 100 µF; CP_Radial_Tantal_D10.5mm_P5.00mm; Voltage Rating 16V; Voltage Tolerance +80% -20%; Mouser Part 647-UVR1C101MDD1TD
C111: 10 µF; CP_Radial_Tantal_D5.0mm_P5.00mm; Voltage Rating 16V; Voltage Tolerance +80% -20%; Mouser Part 647-UVR1H100MDD1TD
CN11: Power DIN connector; Connector_Power_5pin_252167_01
CN12: 6 pin post; CN12_C128D_power
CN13: Power LED; PinHeader_1x03_P2.54mm_Vertical; Mouser Part 538-22-03-2031
CR10, CR11: 1N4001; D_DO-41_SOD81_P12.70mm_Horizontal; Mouser Part 625-1N4001-E3/54
CR13: 251026-01; BRIDGE_RECTIFIER
L5: 251878-01; Noise_Filter_Power_251878_01
R32, R42: 180; R_Axial_DIN0309_L9.0mm_D2.5mm_P12.70mm_Horizontal; Mouser Part 660-MF1/4DCT52R1800F
SW1: Power switch; Power_Switch
SW2: Reset Switch; Switch-Pushbutton
SW3: Disk Reset; Switch-Pushbutton
U2, U20: 4066; DIP-14_W7.62mm; Mouser Part 595-CD74HCT4066E
U8, U61: 74LS08; DIP-14_W7.62mm; Mouser Part 595-SN74LS08N
U9: 74F32; DIP-14_W7.62mm; Mouser Part 595-SN74F32N
U16: 74LS14; DIP-14_W7.62mm; Mouser Part 595-SN74LS14N
U29, U30, U37, U63: 7406; DIP-14_W7.62mm; Mouser Part 595-SN74LS06N
U31: 74LS00; DIP-14_W7.62mm; Mouser Part 595-SN74LS00N
U54: 74LS32; DIP-14_W7.62mm; Mouser Part 595-SN74LS32N
U56: 74LS74; DIP-14_W7.62mm; Mouser Part 595-SN74LS74AN
U57, U60: 7407; DIP-14_W7.62mm; Mouser Part 595-SN74LS07N
U58: 74LS03; DIP-14_W7.62mm; Mouser Part 595-SN74LS03N
U59: L7812; TO-220-3_Horizontal_TabDown; Mouser Part 511-L7812CV

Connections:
9VAC1: CN12.5, CR13.2 (~~), SW1.4; also elsewhere on the board
9VAC2: C96.1, C104.2, CN12.6, CR13.4 (~~), L5.6; also elsewhere on the board
+5V: C8.2, C9.2, C16.2, C29.2, C30.2, C31.2, C37.2, C54.2, C56.2, C57.2, C58.2, C60.2, C68.2, C100.1, C103.1, C107.1, C123.2, C124.2, CN12.4, R32.2, R42.2, SW1.2, U2.14 (VDD), U8.14 (VCC), U9.14 (VCC), U16.14 (VCC), U20.14 (VDD), U29.14 (VCC), U30.14 (VCC), U31.14 (VCC), U37.14 (VCC), U54.14 (VCC), U56.14 (VCC), U57.14 (VCC), U58.14 (VCC), U60.14 (VCC), U61.14 (VCC), U63.14 (VCC); also elsewhere on the board
+9V: C102.1, C106.1, CR11.2 (A), CR13.1 (+); also elsewhere on the board
+12V: C111.1, C116.1, U59.3 (OUT); also elsewhere on the board
GND: C8.1, C9.1, C16.1, C29.1, C30.1, C31.1, C37.1, C54.1, C56.1, C57.1, C58.1, C60.1, C68.1, C96.2, C97.2, C98.2, C99.2, C100.2, C101.2, C102.2, C103.2, C105.2, C106.2, C107.2, C111.2, C115.2, C116.2, C123.1, C124.1, C200.1, C200.2, C201.1, C201.2, CN11.0 (Shield), CN11.2, CN11.4, CN12.1, CN12.3, CN13.2, CR13.3 (-), SW1.0 (GND), SW2.0 (GND), SW3.0 (GND), U2.7 (VSS), U8.7 (GND), U9.7 (GND), U16.7 (GND), U20.7 (VSS), U29.7 (GND), U30.7 (GND), U31.7 (GND), U37.7 (GND), U54.7 (GND), U56.7 (GND), U57.7 (GND), U58.7 (GND), U59.2 (GND), U60.7 (GND), U61.7 (GND), U63.7 (GND); also elsewhere on the board
unnamed: C95.1, CN11.3, L5.5
unnamed: C95.2, CN11.5, L5.3
unnamed: C97.1, L5.4, SW1.3
unnamed: C98.1, CN11.1, L5.1
unnamed: C99.1, L5.2, SW1.1
unnamed: C101.1, C105.1, C115.1, CR10.1 (K), U59.1 (IN)
unnamed: C104.1, CR10.2 (A), CR11.1 (K)
unnamed: CN13.1, R32.1
unnamed: CN13.3, R42.1

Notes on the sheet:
Only C128
Only C128D
User port ground strap. Not labelled on original PCB, mounted at assembly.

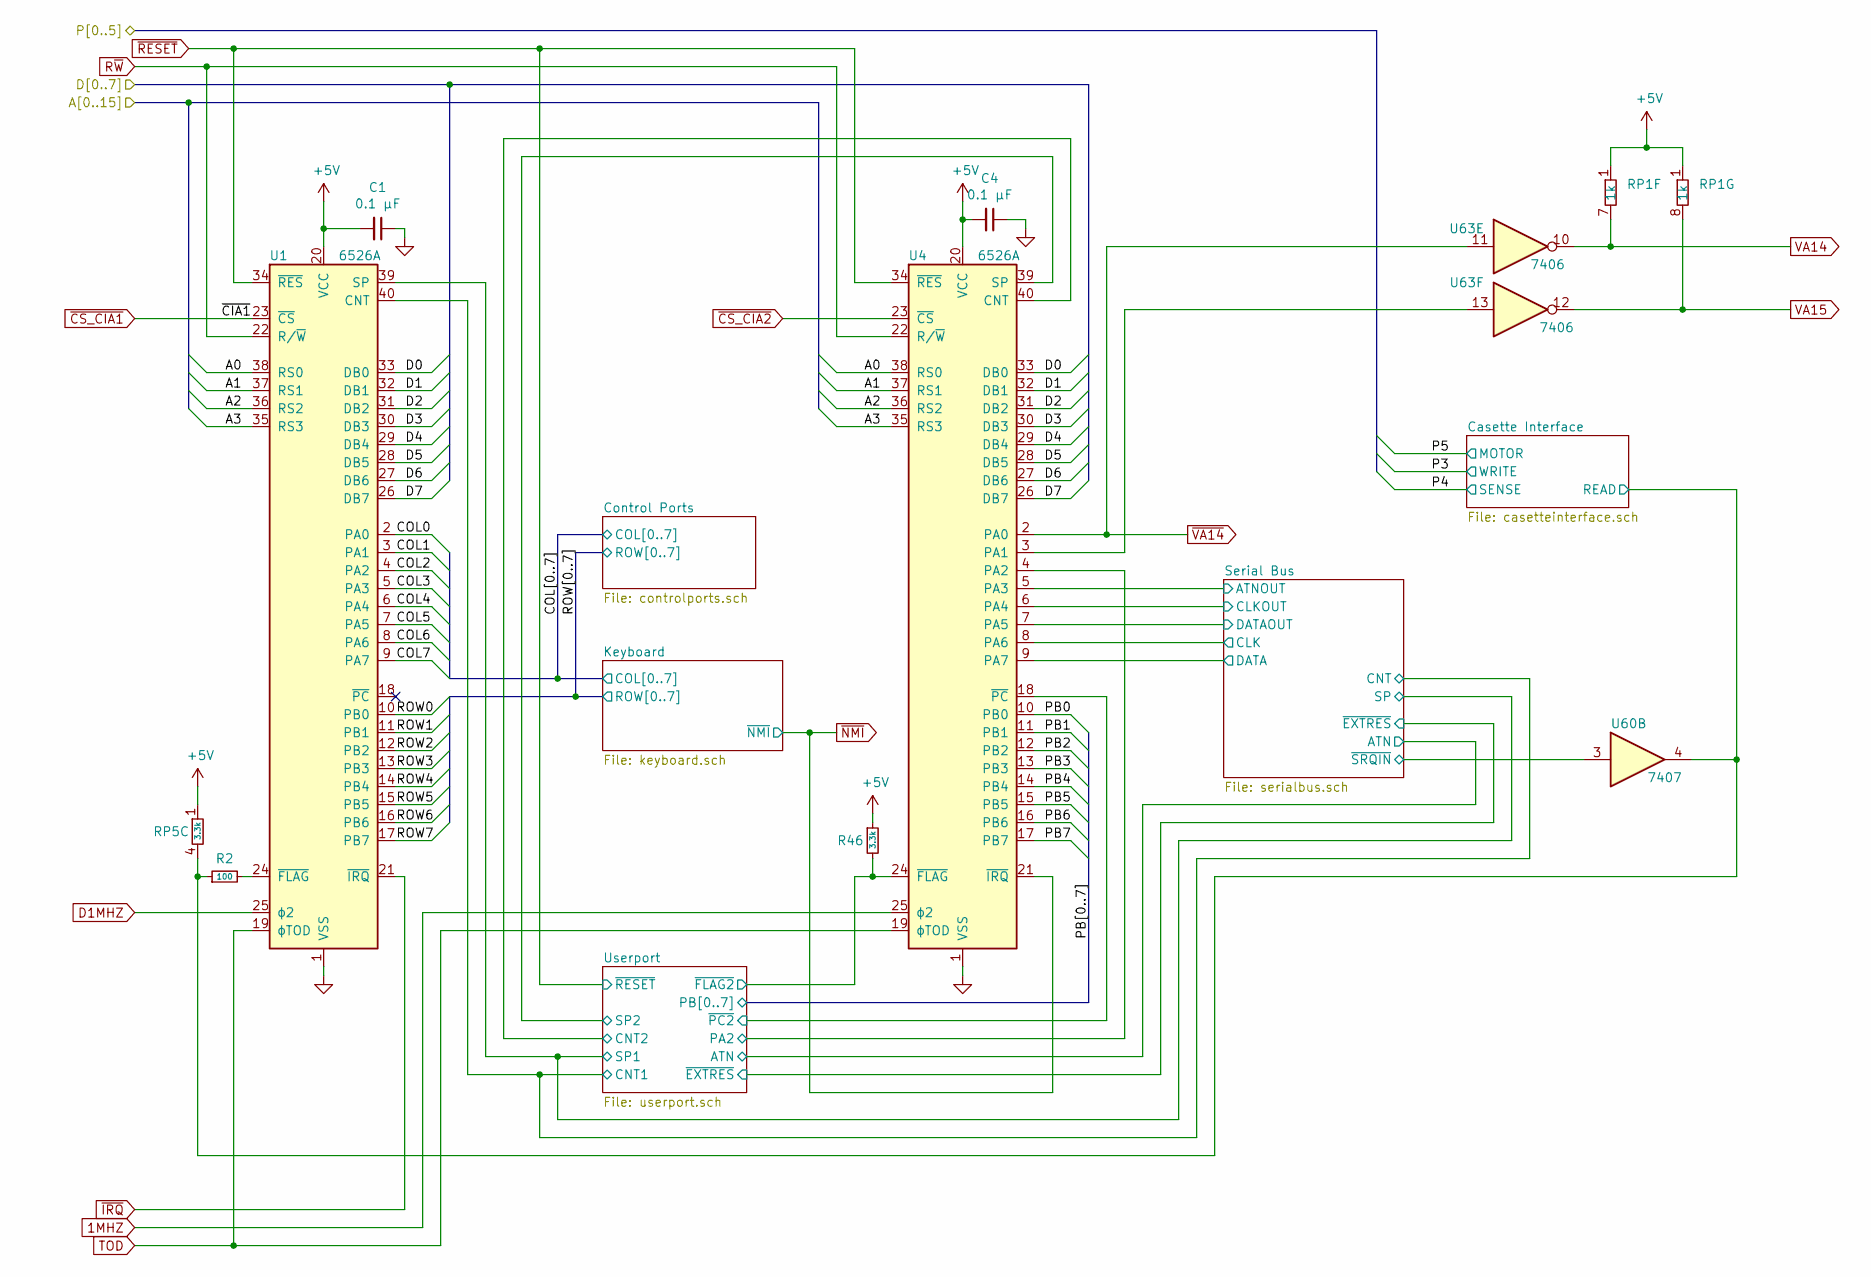
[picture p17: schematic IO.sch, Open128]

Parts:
C1, C4: 0.1 µF; C_Disc_D10.0mm_W2.5mm_P5.00mm; Voltage Rating 25V; Voltage Tolerance +80% -20%; Mouser Part 581-SA105E104MAR
R2: 100; R_Axial_DIN0309_L9.0mm_D2.5mm_P12.70mm_Horizontal; Mouser Part 660-MF1/4DCT52A1000F
R46: 3.3k; R_Axial_DIN0309_L9.0mm_D2.5mm_P12.70mm_Horizontal; Mouser Part 660-MF1/4LCT52R332J
RP1: 1k; R_Array_SIP8; Mouser Part 652-4608X-1LF-1K
RP5: 3.3k; R_Array_SIP8; Mouser Part 652-4608X-1LF-3.3K
U1, U4: 6526A; DIP-40_W15.24mm_Socket
U60: 7407; DIP-14_W7.62mm; Mouser Part 595-SN74LS07N
U63: 7406; DIP-14_W7.62mm; Mouser Part 595-SN74LS06N

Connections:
1MHZ: U4.25 (ϕ2); also elsewhere on the board
+5V: C1.2, C4.2, R46.1, RP1.1 (common), RP5.1 (common), U1.20 (VCC), U4.20 (VCC); also elsewhere on the board
/Address Multiplexing/A0: U1.38 (RS0), U4.38 (RS0); also elsewhere on the board
/Address Multiplexing/A1: U1.37 (RS1), U4.37 (RS1); also elsewhere on the board
/Address Multiplexing/A2: U1.36 (RS2), U4.36 (RS2); also elsewhere on the board
/Address Multiplexing/A3: U1.35 (RS3), U4.35 (RS3); also elsewhere on the board
/CPU 8502/D0: U1.33 (DB0), U4.33 (DB0); also elsewhere on the board
/CPU 8502/D1: U1.32 (DB1), U4.32 (DB1); also elsewhere on the board
/CPU 8502/D2: U1.31 (DB2), U4.31 (DB2); also elsewhere on the board
/CPU 8502/D3: U1.30 (DB3), U4.30 (DB3); also elsewhere on the board
/CPU 8502/D4: U1.29 (DB4), U4.29 (DB4); also elsewhere on the board
/CPU 8502/D5: U1.28 (DB5), U4.28 (DB5); also elsewhere on the board
/CPU 8502/D6: U1.27 (DB6), U4.27 (DB6); also elsewhere on the board
/CPU 8502/D7: U1.26 (DB7), U4.26 (DB7); also elsewhere on the board
/I/O/COL0: U1.2 (PA0); also elsewhere on the board
/I/O/COL1: U1.3 (PA1); also elsewhere on the board
/I/O/COL2: U1.4 (PA2); also elsewhere on the board
/I/O/COL3: U1.5 (PA3); also elsewhere on the board
/I/O/COL4: U1.6 (PA4); also elsewhere on the board
/I/O/COL5: U1.7 (PA5); also elsewhere on the board
/I/O/COL6: U1.8 (PA6); also elsewhere on the board
/I/O/COL7: U1.9 (PA7); also elsewhere on the board
/I/O/Casette Interface/READ: R2.1, RP5.4 (R3), U60.4; also elsewhere on the board
/I/O/PB0: U4.10 (PB0); also elsewhere on the board
/I/O/PB1: U4.11 (PB1); also elsewhere on the board
/I/O/PB2: U4.12 (PB2); also elsewhere on the board
/I/O/PB3: U4.13 (PB3); also elsewhere on the board
/I/O/PB4: U4.14 (PB4); also elsewhere on the board
/I/O/PB5: U4.15 (PB5); also elsewhere on the board
/I/O/PB6: U4.16 (PB6); also elsewhere on the board
/I/O/PB7: U4.17 (PB7); also elsewhere on the board
/I/O/ROW0: U1.10 (PB0); also elsewhere on the board
/I/O/ROW1: U1.11 (PB1); also elsewhere on the board
/I/O/ROW2: U1.12 (PB2); also elsewhere on the board
/I/O/ROW3: U1.13 (PB3); also elsewhere on the board
/I/O/ROW5: U1.15 (PB5); also elsewhere on the board
/I/O/ROW6: U1.16 (PB6); also elsewhere on the board
/I/O/ROW7: U1.17 (PB7); also elsewhere on the board
/I/O/Serial Bus/ATNOUT: U4.5 (PA3); also elsewhere on the board
/I/O/Serial Bus/CLK: U4.8 (PA6); also elsewhere on the board
/I/O/Serial Bus/CLKOUT: U4.6 (PA4); also elsewhere on the board
/I/O/Serial Bus/CNT: U1.40 (CNT); also elsewhere on the board
/I/O/Serial Bus/DATA: U4.9 (PA7); also elsewhere on the board
/I/O/Serial Bus/DATAOUT: U4.7 (PA5); also elsewhere on the board
/I/O/Serial Bus/SP: U1.39 (SP); also elsewhere on the board
/I/O/Serial Bus/~SRQIN: U60.3; also elsewhere on the board
/I/O/Userport/CNT2: U4.40 (CNT); also elsewhere on the board
/I/O/Userport/PA2: U4.4 (PA2); also elsewhere on the board
/I/O/Userport/SP2: U4.39 (SP); also elsewhere on the board
/I/O/Userport/~FLAG2: R46.2, U4.24 (~FLAG); also elsewhere on the board
/I/O/Userport/~PC2: U4.18 (~PC); also elsewhere on the board
D1MHZ: U1.25 (ϕ2); also elsewhere on the board
GND: C1.1, C4.1, U1.1 (VSS), U4.1 (VSS); also elsewhere on the board
unnamed: R2.2, U1.24 (~FLAG)
unnamed: U4.3 (PA1), U63.13
R~W: U1.22 (R/~W), U4.22 (R/~W); also elsewhere on the board
TOD: U1.19 (ϕTOD), U4.19 (ϕTOD); also elsewhere on the board
VA14: RP1.7 (R6), U63.10; also elsewhere on the board
VA15: RP1.8 (R7), U63.12; also elsewhere on the board
~CS_CIA1: U1.23 (~CS); also elsewhere on the board
~CS_CIA2: U4.23 (~CS); also elsewhere on the board
~IRQ: U1.21 (~IRQ); also elsewhere on the board
~LP: U1.14 (PB4); also elsewhere on the board
~NMI: U4.21 (~IRQ); also elsewhere on the board
~RESET: U1.34 (~RES), U4.34 (~RES); also elsewhere on the board
~VA14: U4.2 (PA0), U63.11; also elsewhere on the board

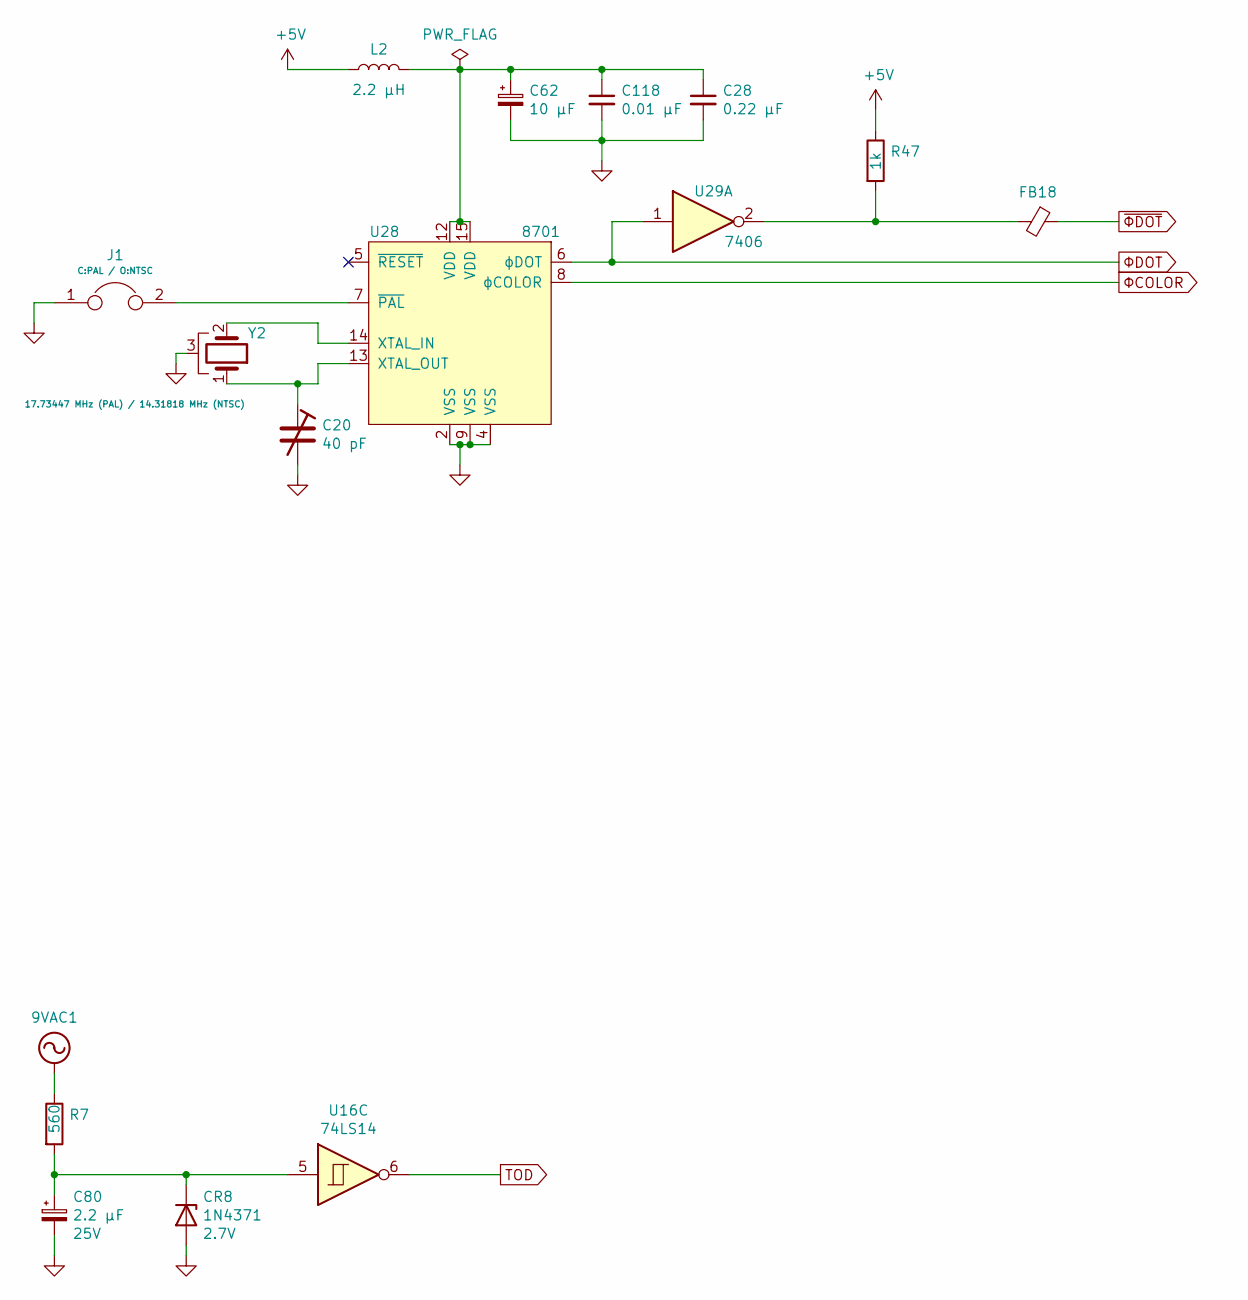
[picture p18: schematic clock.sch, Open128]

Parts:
C20: 40 pF; C_Adjustable_L7.0mm_W4.5mm_P5.00mm
C28: 0.22 µF; C_Disc_D10.0mm_W2.5mm_P5.00mm; Mouser Part 581-SA115E224MAR
C62: 10 µF; CP_Radial_Tantal_D5.0mm_P5.00mm; Voltage Rating 16V; Mouser Part 647-UVR1H100MDD1TD
C80: 2.2 µF; CP_Radial_Tantal_D5.0mm_P5.00mm; Voltage Rating 25V; Mouser Part 647-UVR1H2R2MDD1TD
C118: 0.01 µF; C_Disc_D10.0mm_W2.5mm_P5.00mm; Voltage Rating 25V; Voltage Tolerance +80% -20%; Mouser Part 581-SA105E103M
CR8: 1N4371; D_DO-35_SOD27_P12.70mm_Horizontal; Zener Voltage 2.7V; Mouser Part 512-BZX79C2V7
FB18: Ferrite_Bead_Small; Ferrite_Bead_vertical; Mouser Part 81-BL02RN2R1M2B
J1: C:PAL / O:NTSC; PinHeader_1x02_P2.54mm_Vertical
L2: 2.2 µH; L_Axial_L9.5mm_D4.0mm_P12.70mm_Horizontal_Fastron_SMCC; Mouser Part 871-B78108S1222K
R7: 560; R_Axial_DIN0309_L9.0mm_D2.5mm_P12.70mm_Horizontal; Mouser Part 660-MF1/4DCT52R5600F
R47: 1k; R_Axial_DIN0309_L9.0mm_D2.5mm_P12.70mm_Horizontal; Mouser Part 660-MF1/4DCT52R5600F
U16: 74LS14; DIP-14_W7.62mm; Mouser Part 595-SN74LS14N
U28: 8701; DIP-16_W7.62mm_Socket
U29: 7406; DIP-14_W7.62mm; Mouser Part 595-SN74LS06N
Y2: 17.73447 MHz (PAL) / 14.31818 MHz (NTSC); Crystal_HC49-U_Horizontal_1EP_style2

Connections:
9VAC1: R7.1; also elsewhere on the board
+5V: L2.1, R47.1; also elsewhere on the board
GND: C20.2, C28.2, C62.2, C80.2, C118.2, CR8.2 (A), FB18.3 (GND), J1.1, U28.2 (VSS), U28.4 (VSS), U28.9 (VSS), Y2.3; also elsewhere on the board
unnamed: C20.1, U28.13 (XTAL_OUT), Y2.1
unnamed: C80.1, CR8.1 (K), R7.2, U16.5
unnamed: C28.1, C62.1, C118.1, L2.2, U28.12 (VDD), U28.15 (VDD)
unnamed: FB18.2, R47.2, U29.2
unnamed: J1.2, U28.7 (~PAL)
unnamed: U28.14 (XTAL_IN), Y2.2
TOD: U16.6; also elsewhere on the board
~ΦDOT: FB18.1; also elsewhere on the board
ΦCOLOR: U28.8 (ϕCOLOR); also elsewhere on the board
ΦDOT: U28.6 (ϕDOT), U29.1; also elsewhere on the board

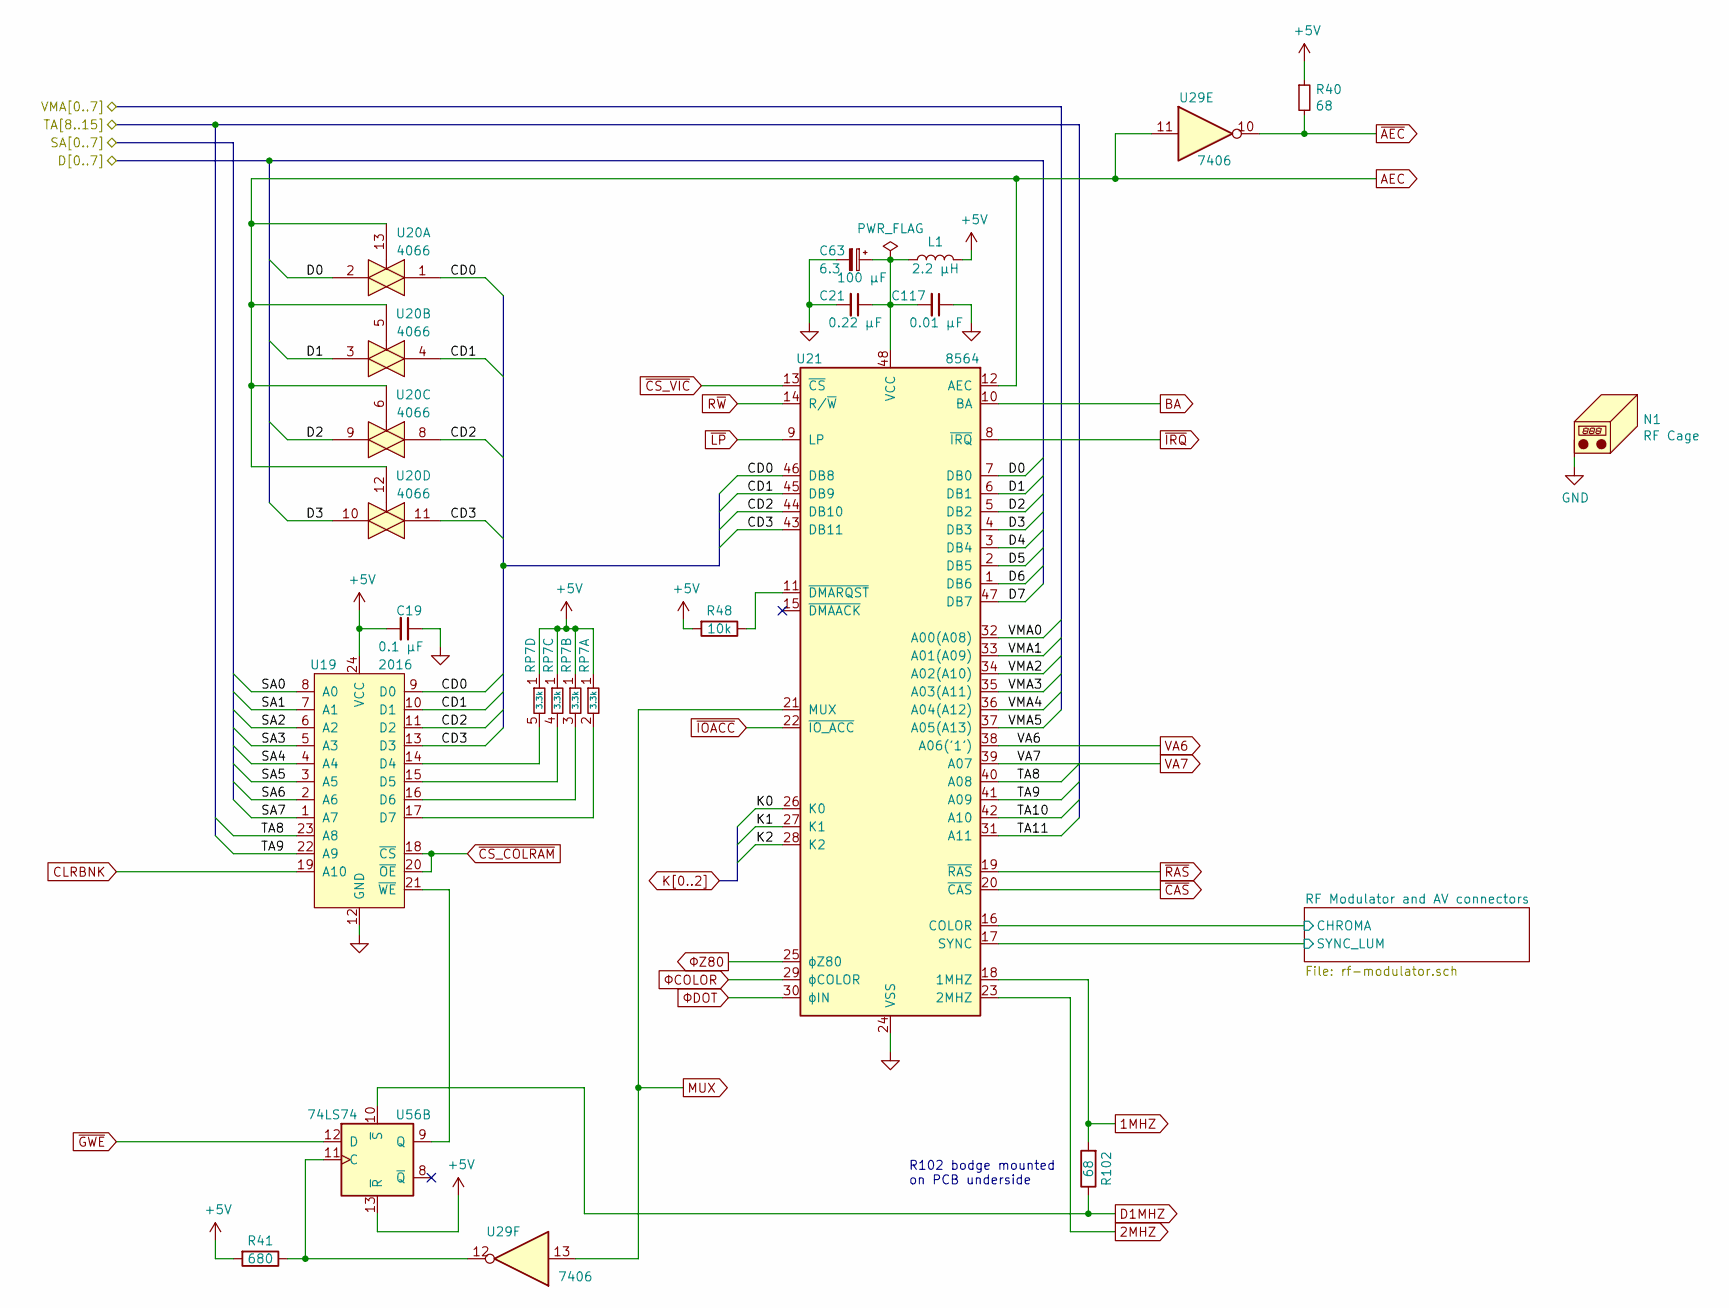
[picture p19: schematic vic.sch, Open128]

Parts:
C19: 0.1 µF; C_Disc_D10.0mm_W2.5mm_P5.00mm; Voltage Rating 25V; Voltage Tolerance +80% -20%; Mouser Part 581-SA105E104MAR
C21: 0.22 µF; C_Disc_D7.5mm_W2.5mm_P5.00mm; Mouser Part 581-SA115E224MAR
C63: 100 µF; CP_Radial_Tantal_D5.0mm_P5.00mm; Voltage Rating 6.3; Voltage Tolerance +80% / -20%; Mouser Part 647-UVR1H100MDD1TD
C117: 0.01 µF; C_Disc_D10.0mm_W2.5mm_P5.00mm; Voltage Rating 25V; Voltage Tolerance +80% -20%; Mouser Part 581-SA105E103M
L1: 2.2 µH; L_Axial_L9.5mm_D4.0mm_P12.70mm_Horizontal_Fastron_SMCC; Mouser Part 871-B78108S1222K
N1: RF Cage; RF_Cage
R40, R102: 68; R_Axial_DIN0309_L9.0mm_D2.5mm_P12.70mm_Horizontal; Mouser Part 660-MF1/4DCT52R68R0F
R41: 680; R_Axial_DIN0309_L9.0mm_D2.5mm_P12.70mm_Horizontal; Mouser Part 660-MF1/4LCT52R681J
R48: 10k; R_Axial_DIN0309_L9.0mm_D2.5mm_P12.70mm_Horizontal; Mouser Part 660-MF1/4LCT52R103J
RP7: 3.3k; R_Array_SIP10; Mouser Part 652-4610X-1LF-3.3K
U19: 2016; DIP-24_W15.24mm_Socket
U20: 4066; DIP-14_W7.62mm; Mouser Part 595-CD74HCT4066E
U21: 8564; DIP-48_W15.24mm_Socket
U29: 7406; DIP-14_W7.62mm; Mouser Part 595-SN74LS06N
U56: 74LS74; DIP-14_W7.62mm; Mouser Part 595-SN74LS74AN

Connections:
1MHZ: R102.2, U21.18 (1MHZ); also elsewhere on the board
2MHZ: U21.23 (2MHZ); also elsewhere on the board
+5V: C19.2, L1.2, R40.1, R41.2, R48.2, RP7.1 (common), U19.24 (VCC), U56.13 (~R); also elsewhere on the board
/Address Multiplexing/SA0: U19.8 (A0); also elsewhere on the board
/Address Multiplexing/SA1: U19.7 (A1); also elsewhere on the board
/Address Multiplexing/SA2: U19.6 (A2); also elsewhere on the board
/Address Multiplexing/SA3: U19.5 (A3); also elsewhere on the board
/Address Multiplexing/SA4: U19.4 (A4); also elsewhere on the board
/Address Multiplexing/SA5: U19.3 (A5); also elsewhere on the board
/Address Multiplexing/SA6: U19.2 (A6); also elsewhere on the board
/Address Multiplexing/SA7: U19.1 (A7); also elsewhere on the board
/Address Multiplexing/TA8: U19.23 (A8), U21.40 (A08); also elsewhere on the board
/Address Multiplexing/TA9: U19.22 (A9), U21.41 (A09); also elsewhere on the board
/Address Multiplexing/TA10: U21.42 (A10); also elsewhere on the board
/Address Multiplexing/TA11: U21.31 (A11); also elsewhere on the board
/Address Multiplexing/VMA0: U21.32 (A00(A08)); also elsewhere on the board
/Address Multiplexing/VMA1: U21.33 (A01(A09)); also elsewhere on the board
/Address Multiplexing/VMA2: U21.34 (A02(A10)); also elsewhere on the board
/Address Multiplexing/VMA3: U21.35 (A03(A11)); also elsewhere on the board
/Address Multiplexing/VMA4: U21.36 (A04(A12)); also elsewhere on the board
/Address Multiplexing/VMA5: U21.37 (A05(A13)); also elsewhere on the board
/CPU 8502/D0: U20.2, U21.7 (DB0); also elsewhere on the board
/CPU 8502/D1: U20.3, U21.6 (DB1); also elsewhere on the board
/CPU 8502/D2: U20.9, U21.5 (DB2); also elsewhere on the board
/CPU 8502/D3: U20.10, U21.4 (DB3); also elsewhere on the board
/CPU 8502/D4: U21.3 (DB4); also elsewhere on the board
/CPU 8502/D5: U21.2 (DB5); also elsewhere on the board
/CPU 8502/D6: U21.1 (DB6); also elsewhere on the board
/CPU 8502/D7: U21.47 (DB7); also elsewhere on the board
/VIC/CD0: U19.9 (D0), U20.1, U21.46 (DB8)
/VIC/CD1: U19.10 (D1), U20.4, U21.45 (DB9)
/VIC/CD2: U19.11 (D2), U20.8, U21.44 (DB10)
/VIC/CD3: U19.13 (D3), U20.11, U21.43 (DB11)
/VIC/RF Modulator and AV connectors/CHROMA: U21.16 (COLOR); also elsewhere on the board
/VIC/RF Modulator and AV connectors/SYNC_LUM: U21.17 (SYNC); also elsewhere on the board
AEC: U20.5, U20.6, U20.12, U20.13, U21.12 (AEC), U29.11; also elsewhere on the board
BA: U21.10 (BA); also elsewhere on the board
CLRBNK: U19.19 (A10); also elsewhere on the board
D1MHZ: R102.1, U56.10 (~S); also elsewhere on the board
GND: C19.1, C21.2, C63.2, C117.1, N1.1, U19.12 (GND), U21.24 (VSS); also elsewhere on the board
K0: U21.26 (K0); also elsewhere on the board
K1: U21.27 (K1); also elsewhere on the board
K2: U21.28 (K2); also elsewhere on the board
MUX: U21.21 (MUX), U29.13; also elsewhere on the board
unnamed: C21.1, C63.1, C117.2, L1.1, U21.48 (VCC)
unnamed: R41.1, U29.12, U56.11 (C)
unnamed: R48.1, U21.11 (~DMARQST)
unnamed: RP7.2 (R1), U19.17 (D7)
unnamed: RP7.3 (R2), U19.16 (D6)
unnamed: RP7.4 (R3), U19.15 (D5)
unnamed: RP7.5 (R4), U19.14 (D4)
unnamed: U19.21 (~WE), U56.9 (Q)
R~W: U21.14 (R/~W); also elsewhere on the board
VA6: U21.38 (A06('1')); also elsewhere on the board
VA7: U21.39 (A07); also elsewhere on the board
~AEC: R40.2, U29.10; also elsewhere on the board
~CAS: U21.20 (~CAS); also elsewhere on the board
~CS_COLRAM: U19.18 (~CS), U19.20 (~OE); also elsewhere on the board
~CS_VIC: U21.13 (~CS); also elsewhere on the board
~GWE: U56.12 (D); also elsewhere on the board
~IOACC: U21.22 (~IO_ACC); also elsewhere on the board
~IRQ: U21.8 (~IRQ); also elsewhere on the board
~LP: U21.9 (LP); also elsewhere on the board
~RAS: U21.19 (~RAS); also elsewhere on the board
ΦCOLOR: U21.29 (ϕCOLOR); also elsewhere on the board
ΦDOT: U21.30 (ϕIN); also elsewhere on the board
ΦZ80: U21.25 (ϕZ80); also elsewhere on the board

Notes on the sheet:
R102 bodge mounted on PCB underside

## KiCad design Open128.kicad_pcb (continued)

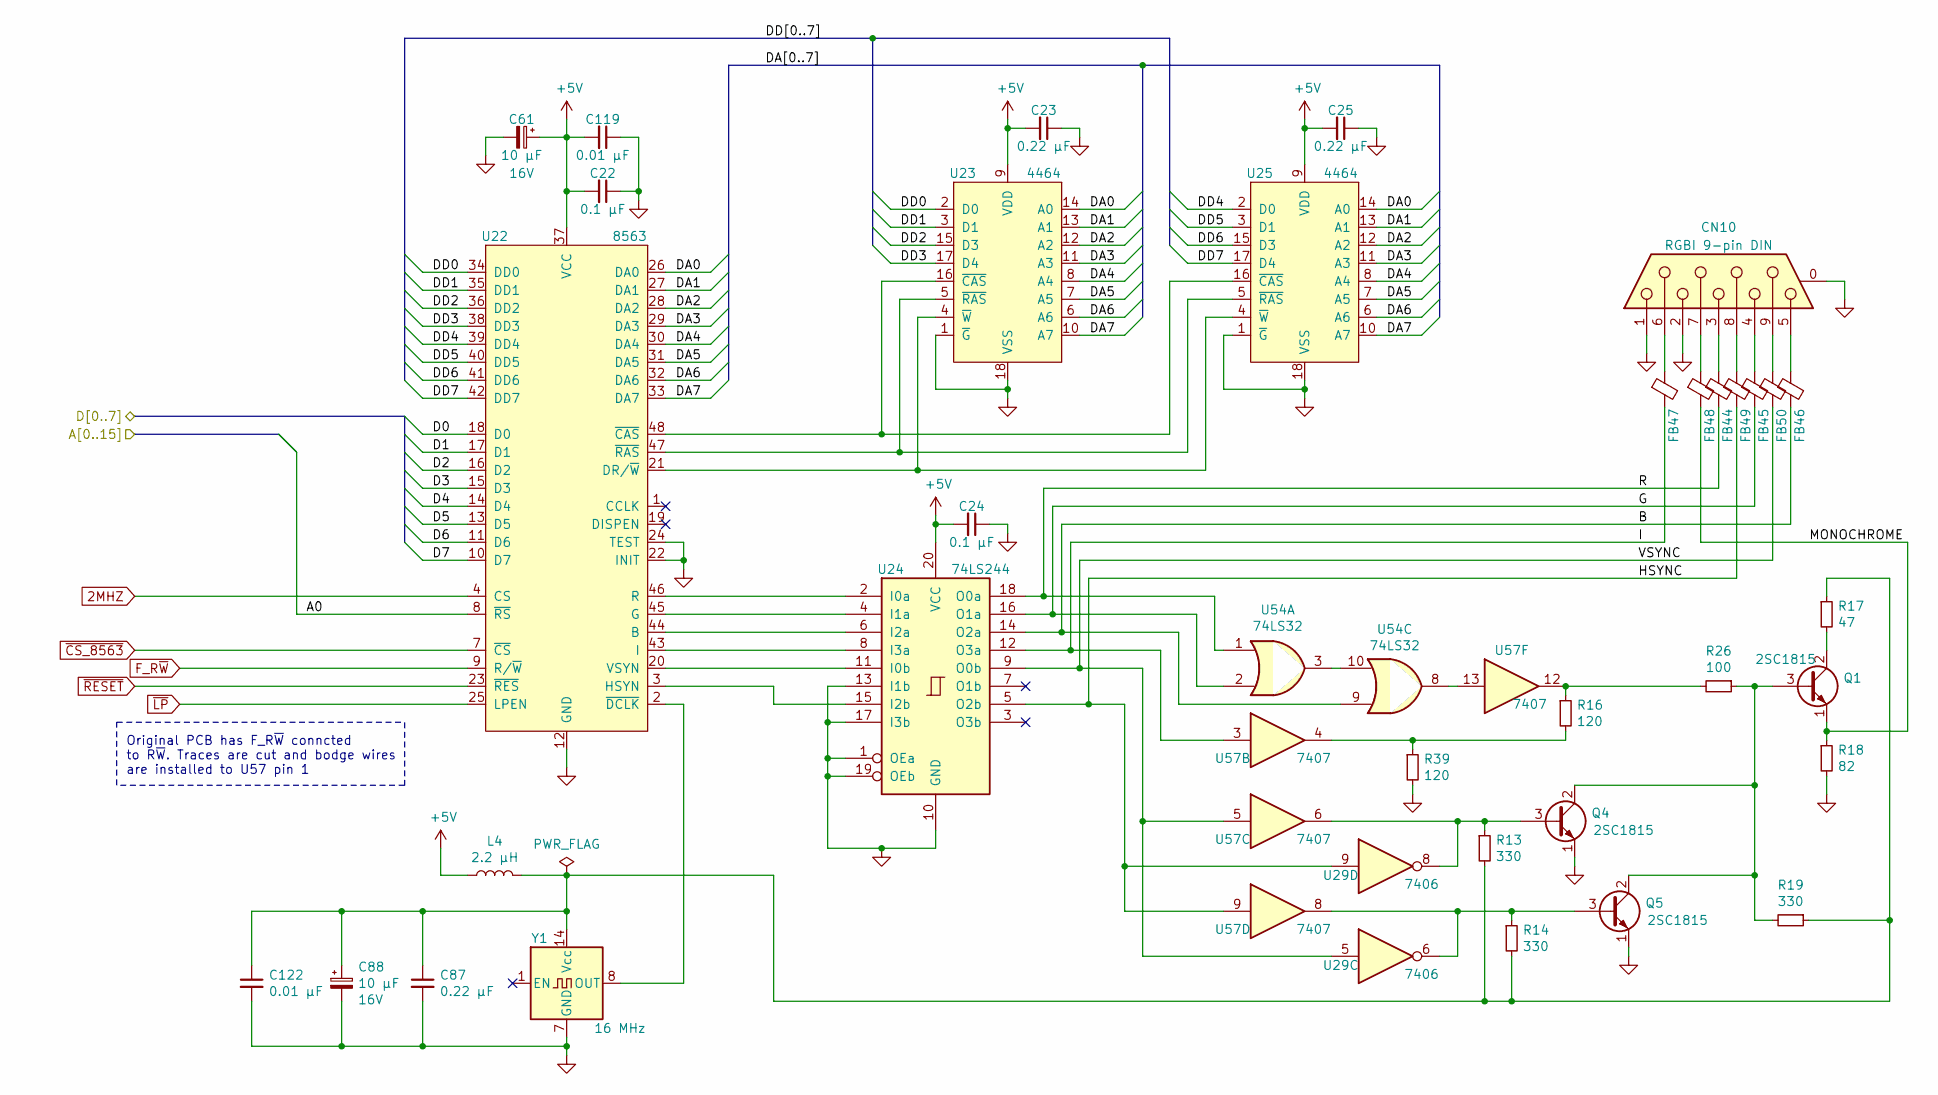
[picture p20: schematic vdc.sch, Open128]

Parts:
C22, C24: 0.1 µF; C_Disc_D10.0mm_W2.5mm_P5.00mm; Voltage Rating 25V; Voltage Tolerance +80% -20%; Mouser Part 581-SA105E104MAR
C23, C25, C87: 0.22 µF; C_Disc_D10.0mm_W2.5mm_P5.00mm; Mouser Part 581-SA115E224MAR
C61, C88: 10 µF; CP_Radial_Tantal_D5.0mm_P5.00mm; Voltage Tolerance 16V; Mouser Part 647-UVR1H100MDD1TD
C119, C122: 0.01 µF; C_Disc_D10.0mm_W2.5mm_P5.00mm; Voltage Rating 25V; Voltage Tolerance +80% -20%; Mouser Part 581-SA105E103M
CN10: RGBI 9-pin DIN; DSUB-9_Male_Horizontal_P2.77x2.84mm_EdgePinOffset7.70mm_Hou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; Mouser Part 636-182-009-213R181
FB44, FB45, FB46, FB47, FB48, FB49, FB50: Ferrite_Bead_Small; Ferrite_Bead_vertical; Mouser Part 81-BL02RN2R1M2B
L4: 2.2 µH; L_Axial_L9.5mm_D4.0mm_P12.70mm_Horizontal_Fastron_SMCC; Mouser Part 871-B78108S1222K
Q1, Q4, Q5: 2SC1815; TO-92_Inline_Wide; Mouser Part 512-KSC1815YTA
R13, R14: 330; R_Axial_DIN0411_L9.9mm_D3.6mm_P12.70mm_Horizontal; Mouser Part 660-MF1/2LCT52R331J
R16, R39: 120; R_Axial_DIN0309_L9.0mm_D2.5mm_P12.70mm_Horizontal; Mouser Part 660-MF1/4DCT52R1200F
R17: 47; R_Axial_DIN0309_L9.0mm_D2.5mm_P12.70mm_Horizontal; Mouser Part 660-MF1/4DCT52R47R0F
R18: 82; R_Axial_DIN0309_L9.0mm_D2.5mm_P12.70mm_Horizontal; Mouser Part 660-MF1/4DCT52R82R0F
R19: 330; R_Axial_DIN0309_L9.0mm_D2.5mm_P12.70mm_Horizontal; Mouser Part 660-MF1/2LCT52R331J
R26: 100; R_Axial_DIN0309_L9.0mm_D2.5mm_P12.70mm_Horizontal; Mouser Part 660-MF1/4DCT52A1000F
U22: 8563; DIP-48_W15.24mm_Socket
U23, U25: 4464; DIP-18_W7.62mm_Socket
U24: 74LS244; DIP-20_W7.62mm; Mouser Part 595-SN74LS244N
U29: 7406; DIP-14_W7.62mm; Mouser Part 595-SN74LS06N
U54: 74LS32; DIP-14_W7.62mm; Mouser Part 595-SN74LS32N
U57: 7407; DIP-14_W7.62mm; Mouser Part 595-SN74LS07N
Y1: 16 MHz; Oscillator_DIP-14; Mouser Part 774-MXO45-2C-16M0000

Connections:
2MHZ: U22.4 (CS); also elsewhere on the board
+5V: C22.2, C23.2, C24.2, C25.2, C61.1, C119.2, L4.1, U22.37 (VCC), U23.9 (VDD), U24.20 (VCC), U25.9 (VDD); also elsewhere on the board
/Address Multiplexing/A0: U22.8 (~RS); also elsewhere on the board
/CPU 8502/D0: U22.18 (D0); also elsewhere on the board
/CPU 8502/D1: U22.17 (D1); also elsewhere on the board
/CPU 8502/D2: U22.16 (D2); also elsewhere on the board
/CPU 8502/D3: U22.15 (D3); also elsewhere on the board
/CPU 8502/D4: U22.14 (D4); also elsewhere on the board
/CPU 8502/D5: U22.13 (D5); also elsewhere on the board
/CPU 8502/D6: U22.11 (D6); also elsewhere on the board
/CPU 8502/D7: U22.10 (D7); also elsewhere on the board
/VDC/B: FB46.2, U24.14 (O2a), U54.9
/VDC/DA0: U22.26 (DA0), U23.14 (A0), U25.14 (A0)
/VDC/DA1: U22.27 (DA1), U23.13 (A1), U25.13 (A1)
/VDC/DA2: U22.28 (DA2), U23.12 (A2), U25.12 (A2)
/VDC/DA3: U22.29 (DA3), U23.11 (A3), U25.11 (A3)
/VDC/DA4: U22.30 (DA4), U23.8 (A4), U25.8 (A4)
/VDC/DA5: U22.31 (DA5), U23.7 (A5), U25.7 (A5)
/VDC/DA6: U22.32 (DA6), U23.6 (A6), U25.6 (A6)
/VDC/DA7: U22.33 (DA7), U23.10 (A7), U25.10 (A7)
/VDC/DD0: U22.34 (DD0), U23.2 (D0)
/VDC/DD1: U22.35 (DD1), U23.3 (D1)
/VDC/DD2: U22.36 (DD2), U23.15 (D3)
/VDC/DD3: U22.38 (DD3), U23.17 (D4)
/VDC/DD4: U22.39 (DD4), U25.2 (D0)
/VDC/DD5: U22.40 (DD5), U25.3 (D1)
/VDC/DD6: U22.41 (DD6), U25.15 (D3)
/VDC/DD7: U22.42 (DD7), U25.17 (D4)
/VDC/G: FB45.2, U24.16 (O1a), U54.2
/VDC/HSYNC: FB49.2, U24.5 (O2b), U29.9, U57.9
/VDC/I: FB47.2, U24.12 (O3a), U57.3
/VDC/MONOCHROME: FB48.2, Q1.1 (E), R18.1
/VDC/R: FB44.2, U24.18 (O0a), U54.1
/VDC/VSYNC: FB50.2, U24.9 (O0b), U29.5, U57.5
F_R~W: U22.9 (R/~W); also elsewhere on the board
GND: C22.1, C23.1, C24.1, C25.1, C61.2, C87.2, C88.2, C119.1, C122.2, CN10.0 (PAD), CN10.1, CN10.2, FB44.3 (GND), FB45.3 (GND), FB46.3 (GND), FB47.3 (GND), FB48.3 (GND), FB49.3 (GND), FB50.3 (GND), Q4.1 (E), Q5.1 (E), R18.2, R39.2, U22.12 (GND), U22.22 (INIT), U22.24 (TEST), U23.1 (~G), U23.18 (VSS), U24.1 (OEa), U24.10 (GND), U24.13 (I1b), U24.17 (I3b), U24.19 (OEb), U25.1 (~G), U25.18 (VSS), Y1.7 (GND); also elsewhere on the board
unnamed: C87.1, C88.1, C122.1, L4.2, R13.2, R14.2, R17.1, R19.1, Y1.14 (Vcc)
unnamed: CN10.3, FB44.1
unnamed: CN10.4, FB45.1
unnamed: CN10.5, FB46.1
unnamed: CN10.6, FB47.1
unnamed: CN10.7, FB48.1
unnamed: CN10.8, FB49.1
unnamed: CN10.9, FB50.1
unnamed: Q1.2 (C), R17.2
unnamed: Q1.3 (B), Q4.2 (C), Q5.2 (C), R19.2, R26.1
unnamed: Q4.3 (B), R13.1, U29.8, U57.6
unnamed: Q5.3 (B), R14.1, U29.6, U57.8
unnamed: R16.1, R26.2, U57.12
unnamed: R16.2, R39.1, U57.4
unnamed: U22.2 (~DCLK), Y1.8 (OUT)
unnamed: U22.3 (HSYN), U24.15 (I2b)
unnamed: U22.20 (VSYN), U24.11 (I0b)
unnamed: U22.21 (DR/~W), U23.4 (~W), U25.4 (~W)
unnamed: U22.43 (I), U24.8 (I3a)
unnamed: U22.44 (B), U24.6 (I2a)
unnamed: U22.45 (G), U24.4 (I1a)
unnamed: U22.46 (R), U24.2 (I0a)
unnamed: U22.47 (~RAS), U23.5 (~RAS), U25.5 (~RAS)
unnamed: U22.48 (~CAS), U23.16 (~CAS), U25.16 (~CAS)
unnamed: U54.8, U57.13
unnamed: U54.3, U54.10
~CS_8563: U22.7 (~CS); also elsewhere on the board
~LP: U22.25 (LPEN); also elsewhere on the board
~RESET: U22.23 (~RES); also elsewhere on the board

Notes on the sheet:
Original PCB has F_R~W~ conncted to R~W~. Traces are cut and bodge wires are installed to U57 pin 1

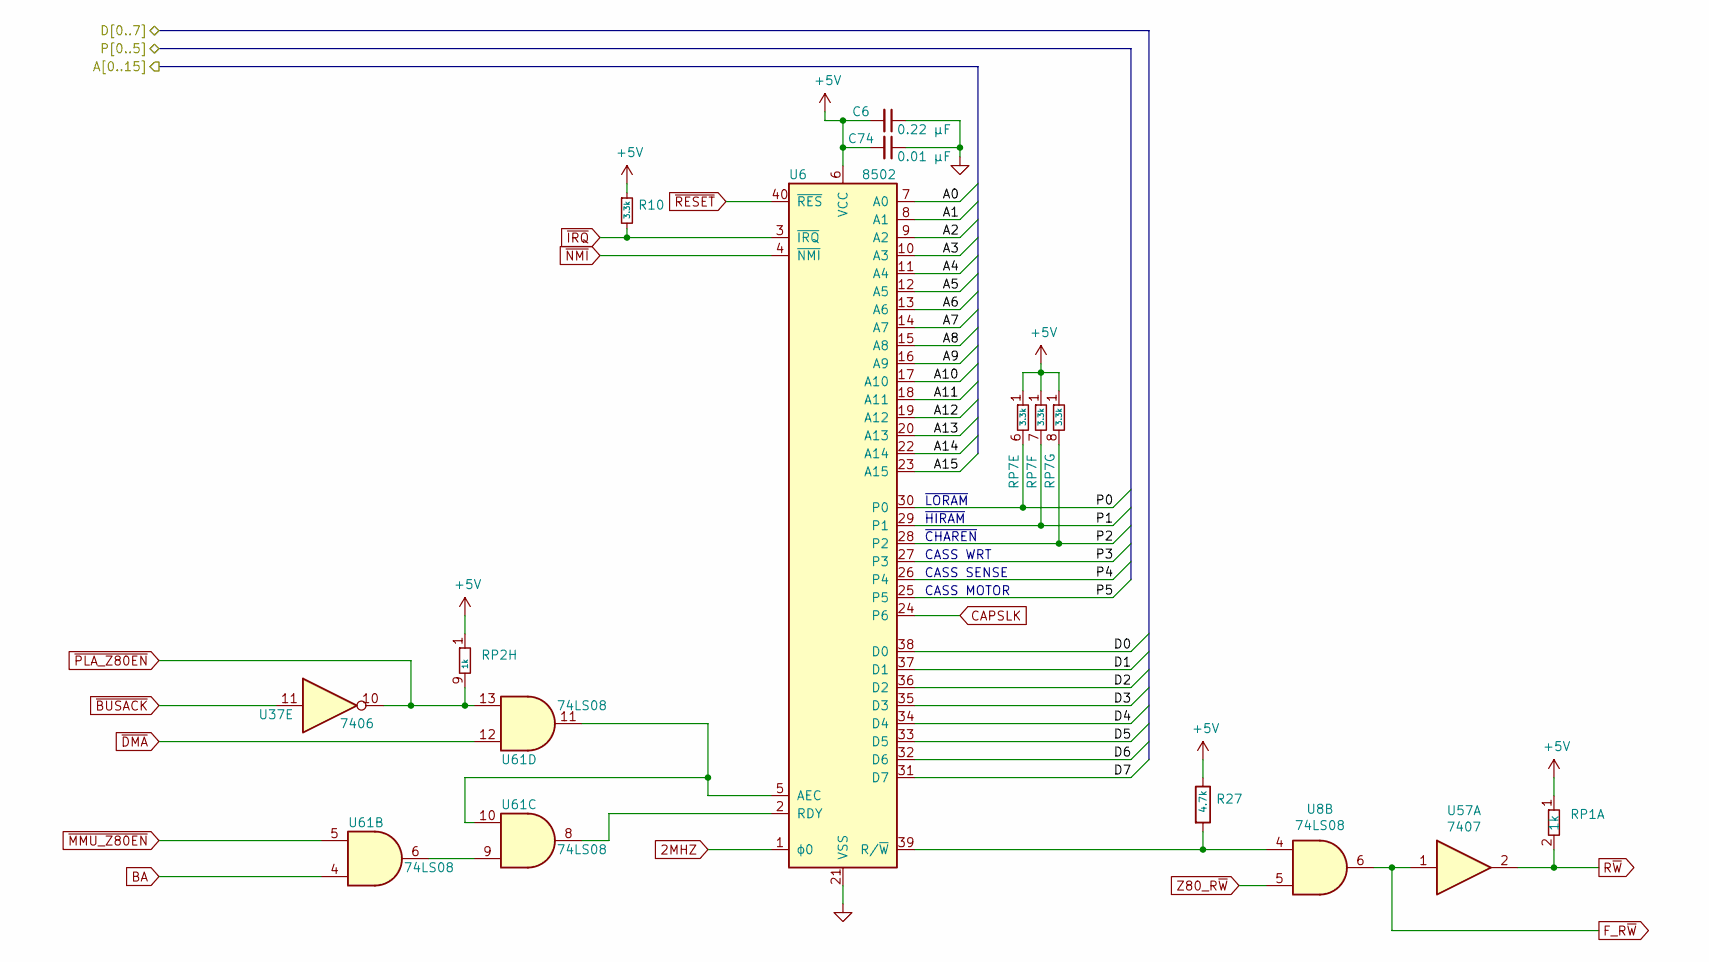
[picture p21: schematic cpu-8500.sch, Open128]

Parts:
C6: 0.22 µF; C_Disc_D10.0mm_W2.5mm_P5.00mm; Mouser Part 581-SA115E224MAR
C74: 0.01 µF; C_Disc_D10.0mm_W2.5mm_P5.00mm; Voltage Rating 25V; Voltage Tolerance +80% -20%; Mouser Part 581-SA105E103M
R10: 3.3k; R_Axial_DIN0309_L9.0mm_D2.5mm_P12.70mm_Horizontal; Mouser Part 660-MF1/4LCT52R332J
R27: 4.7k; R_Axial_DIN0309_L9.0mm_D2.5mm_P12.70mm_Horizontal; Mouser Part 660-MF1/4LCT52R472J
RP1: 1k; R_Array_SIP8; Mouser Part 652-4608X-1LF-1K
RP2: 1k; R_Array_SIP9; Mouser Part 652-4609X-1LF-1K
RP7: 3.3k; R_Array_SIP10; Mouser Part 652-4610X-1LF-3.3K
U6: 8502; DIP-40_W15.24mm_Socket
U8, U61: 74LS08; DIP-14_W7.62mm; Mouser Part 595-SN74LS08N
U37: 7406; DIP-14_W7.62mm; Mouser Part 595-SN74LS06N
U57: 7407; DIP-14_W7.62mm; Mouser Part 595-SN74LS07N

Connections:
2MHZ: U6.1 (ϕ0); also elsewhere on the board
+5V: C6.2, C74.2, R10.1, R27.1, RP1.1 (common), RP2.1 (common), RP7.1 (common), U6.6 (VCC); also elsewhere on the board
/Address Multiplexing/A0: U6.7 (A0); also elsewhere on the board
/Address Multiplexing/A1: U6.8 (A1); also elsewhere on the board
/Address Multiplexing/A2: U6.9 (A2); also elsewhere on the board
/Address Multiplexing/A3: U6.10 (A3); also elsewhere on the board
/Address Multiplexing/A4: U6.11 (A4); also elsewhere on the board
/Address Multiplexing/A5: U6.12 (A5); also elsewhere on the board
/Address Multiplexing/A6: U6.13 (A6); also elsewhere on the board
/Address Multiplexing/A7: U6.14 (A7); also elsewhere on the board
/Address Multiplexing/A8: U6.15 (A8); also elsewhere on the board
/Address Multiplexing/A9: U6.16 (A9); also elsewhere on the board
/Address Multiplexing/A10: U6.17 (A10); also elsewhere on the board
/Address Multiplexing/A11: U6.18 (A11); also elsewhere on the board
/Address Multiplexing/A12: U6.19 (A12); also elsewhere on the board
/Address Multiplexing/A13: U6.20 (A13); also elsewhere on the board
/Address Multiplexing/A14: U6.22 (A14); also elsewhere on the board
/Address Multiplexing/A15: U6.23 (A15); also elsewhere on the board
/CPU 8502/D0: U6.38 (D0); also elsewhere on the board
/CPU 8502/D1: U6.37 (D1); also elsewhere on the board
/CPU 8502/D2: U6.36 (D2); also elsewhere on the board
/CPU 8502/D3: U6.35 (D3); also elsewhere on the board
/CPU 8502/D4: U6.34 (D4); also elsewhere on the board
/CPU 8502/D5: U6.33 (D5); also elsewhere on the board
/CPU 8502/D6: U6.32 (D6); also elsewhere on the board
/CPU 8502/D7: U6.31 (D7); also elsewhere on the board
/CPU 8502/P0: RP7.6 (R5), U6.30 (P0); also elsewhere on the board
/CPU 8502/P1: RP7.7 (R6), U6.29 (P1); also elsewhere on the board
/CPU 8502/P2: RP7.8 (R7), U6.28 (P2); also elsewhere on the board
/CPU 8502/P3: U6.27 (P3); also elsewhere on the board
/CPU 8502/P4: U6.26 (P4); also elsewhere on the board
/CPU 8502/P5: U6.25 (P5); also elsewhere on the board
BA: U61.4; also elsewhere on the board
CAPSLK: U6.24 (P6); also elsewhere on the board
F_R~W: U8.6, U57.1; also elsewhere on the board
GND: C6.1, C74.1, U6.21 (VSS); also elsewhere on the board
unnamed: R27.2, U6.39 (R/~W), U8.4
unnamed: U6.2 (RDY), U61.8
unnamed: U6.5 (AEC), U61.10, U61.11
unnamed: U61.6, U61.9
R~W: RP1.2 (R1), U57.2; also elsewhere on the board
Z80_R~W: U8.5; also elsewhere on the board
~BUSACK: U37.11; also elsewhere on the board
~DMA: U61.12; also elsewhere on the board
~IRQ: R10.2, U6.3 (~IRQ); also elsewhere on the board
~MMU_Z80EN: U61.5; also elsewhere on the board
~NMI: U6.4 (~NMI); also elsewhere on the board
~PLA_Z80EN: RP2.9 (R8), U37.10, U61.13; also elsewhere on the board
~RESET: U6.40 (~RES); also elsewhere on the board

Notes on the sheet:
~LORAM
~HIRAM
~CHAREN
CASS WRT
CASS SENSE
CASS MOTOR

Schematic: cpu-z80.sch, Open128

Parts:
C10, C12, C13: 0.1 µF; C_Disc_D10.0mm_W2.5mm_P5.00mm; Voltage Rating 25V; Voltage Tolerance +80% -20%; Mouser Part 581-SA105E104MAR
C110: 0.01 µF; C_Disc_D10.0mm_W2.5mm_P5.00mm; Voltage Rating 25V; Voltage Tolerance +80% -20%; Mouser Part 581-SA105E103M
Q6: 2SC1815; TO-92_Inline_Wide; Mouser Part 512-KSC1815YTA
R8: 3.3k; R_Axial_DIN0309_L9.0mm_D2.5mm_P12.70mm_Horizontal; Mouser Part 660-MF1/4LCT52R332J
R34: 10k; R_Axial_DIN0309_L9.0mm_D2.5mm_P12.70mm_Horizontal; Mouser Part 660-MF1/4LCT52R103J
R35: 100; R_Axial_DIN0309_L9.0mm_D2.5mm_P12.70mm_Horizontal; Mouser Part 660-MF1/4DCT52A1000F
R45: 1.2k; R_Axial_DIN0309_L9.0mm_D2.5mm_P12.70mm_Horizontal; Mouser Part 660-MF1/4LCT52R122J
R101: 1k; R_Axial_DIN0309_L9.0mm_D2.5mm_P12.70mm_Horizontal; Mouser Part 660-MF1/4LCT52R102J
RP7: 3.3k; R_Array_SIP10; Mouser Part 652-4610X-1LF-3.3K
U8: 74LS08; DIP-14_W7.62mm; Mouser Part 595-SN74LS08N
U10: Z80; DIP-40_W15.24mm_Socket
U12: 74LS373; DIP-20_W7.62mm; Mouser Part 595-SN74LS373N
U13: 74LS244; DIP-20_W7.62mm; Mouser Part 595-SN74LS244N
U31: 74LS00; DIP-14_W7.62mm; Mouser Part 595-SN74LS00N
U37: 7406; DIP-14_W7.62mm; Mouser Part 595-SN74LS06N
U56: 74LS74; DIP-14_W7.62mm; Mouser Part 595-SN74LS74AN
U60: 7407; DIP-14_W7.62mm; Mouser Part 595-SN74LS07N

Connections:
+5V: C10.2, C12.2, C13.2, C110.2, R8.2, R34.2, R35.2, RP7.1 (common), U10.11 (VCC), U12.20 (VCC), U13.20 (VCC), U56.1 (~R), U56.4 (~S); also elsewhere on the board
+12V: R45.2; also elsewhere on the board
/Address Multiplexing/A0: U10.30 (A0); also elsewhere on the board
/Address Multiplexing/A1: U10.31 (A1); also elsewhere on the board
/Address Multiplexing/A2: U10.32 (A2); also elsewhere on the board
/Address Multiplexing/A3: U10.33 (A3); also elsewhere on the board
/Address Multiplexing/A4: U10.34 (A4); also elsewhere on the board
/Address Multiplexing/A5: U10.35 (A5); also elsewhere on the board
/Address Multiplexing/A6: U10.36 (A6); also elsewhere on the board
/Address Multiplexing/A7: U10.37 (A7); also elsewhere on the board
/Address Multiplexing/A8: U10.38 (A8); also elsewhere on the board
/Address Multiplexing/A9: U10.39 (A9); also elsewhere on the board
/Address Multiplexing/A10: U10.40 (A10); also elsewhere on the board
/Address Multiplexing/A11: U10.1 (A11); also elsewhere on the board
/Address Multiplexing/A12: U10.2 (A12); also elsewhere on the board
/Address Multiplexing/A13: U10.3 (A13); also elsewhere on the board
/Address Multiplexing/A14: U10.4 (A14); also elsewhere on the board
/Address Multiplexing/A15: U10.5 (A15); also elsewhere on the board
/CPU 8502/D0: U12.3 (D0), U13.3 (O3b); also elsewhere on the board
/CPU 8502/D1: U12.4 (D1), U13.5 (O2b); also elsewhere on the board
/CPU 8502/D2: U12.7 (D2), U13.7 (O1b); also elsewhere on the board
/CPU 8502/D3: U12.8 (D3), U13.9 (O0b); also elsewhere on the board
/CPU 8502/D4: U12.13 (D4), U13.12 (O3a); also elsewhere on the board
/CPU 8502/D5: U12.14 (D5), U13.14 (O2a); also elsewhere on the board
/CPU 8502/D6: U12.17 (D6), U13.16 (O1a); also elsewhere on the board
/CPU 8502/D7: U12.18 (D7), U13.18 (O0a); also elsewhere on the board
/CPU Z80/ZD0: U10.14 (D0), U12.2 (O0), U13.17 (I3b)
/CPU Z80/ZD1: U10.15 (D1), U12.5 (O1), U13.15 (I2b)
/CPU Z80/ZD2: U10.12 (D2), U12.6 (O2), U13.13 (I1b)
/CPU Z80/ZD3: U10.8 (D3), U12.9 (O3), U13.11 (I0b)
/CPU Z80/ZD4: U10.7 (D4), U12.12 (O4), U13.8 (I3a)
/CPU Z80/ZD5: U10.9 (D5), U12.15 (O5), U13.6 (I2a)
/CPU Z80/ZD6: U10.10 (D6), U12.16 (O6), U13.4 (I1a)
/CPU Z80/ZD7: U10.13 (D7), U12.19 (O7), U13.2 (I0a)
BA: U60.1; also elsewhere on the board
D1MHZ: U12.11 (LE), U56.3 (C); also elsewhere on the board
GAEC: U31.13; also elsewhere on the board
GND: C10.1, C12.1, C13.1, C110.1, R101.1, U10.29 (GND), U12.10 (GND), U13.10 (GND); also elsewhere on the board
unnamed: Q6.1 (E), U10.6 (~CLK~), U60.10
unnamed: Q6.2 (C), R35.1
unnamed: Q6.3 (B), R45.1, R101.2, U60.12
unnamed: R8.1, U10.22 (~WR~), U31.1
unnamed: R34.1, U10.17 (~NMI~), U10.24 (~WAIT~)
unnamed: RP7.9 (R8), U10.25 (~BUSRQ~), U37.6, U37.8, U60.2
unnamed: U10.21 (~RD~), U12.1 (OE)
unnamed: U31.2, U31.6
unnamed: U31.3, U31.4, U56.2 (D)
unnamed: U31.5, U56.6 (~Q)
unnamed: U31.12, U56.5 (Q)
unnamed: U8.3, U37.5
Z80_R~W: U13.1 (OEa), U13.19 (OEb), U31.11; also elsewhere on the board
~AEC: U8.2; also elsewhere on the board
~BUSACK: U10.23 (~BUSACK~); also elsewhere on the board
~IRQ: U10.16 (~INT~); also elsewhere on the board
~M1: U10.27 (~M1~); also elsewhere on the board
~MMU_Z80EN: U37.9; also elsewhere on the board
~PLA_Z80EN: U8.1; also elsewhere on the board
~RESET: U10.26 (~RESET~); also elsewhere on the board
~Z80_IO: RP7.10 (R9), U10.20 (~IORQ~); also elsewhere on the board
ΦZ80: U60.11, U60.13; also elsewhere on the board

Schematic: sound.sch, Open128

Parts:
C5, C86: 0.1 µF; C_Disc_D10.0mm_W2.5mm_P5.00mm; Voltage Rating 25V; Voltage Tolerance +80% -20%; Mouser Part 581-SA105E104MAR
C81: 1000 pF; C_Disc_D10.0mm_W2.5mm_P5.00mm; Voltage Rating 50V; Voltage Tolerance 10%; Mouser Part 581-SA101C102KAN
C82, C83, C112: 470 pF; C_Disc_D10.0mm_W2.5mm_P5.00mm; Mouser Part 581-SA101A471JAR
C84: 220 pF; C_Disc_D10.0mm_W2.5mm_P5.00mm; Mouser Part 581-SA102C221KAA
C85: 10 µF; CP_Radial_Tantal_D5.0mm_P5.00mm; Voltage Tolerance 16V; Mouser Part 647-UVR1H100MDD1TD
C108, C109: 1800 pF; C_Disc_D10.0mm_W2.5mm_P5.00mm; Mouser Part 581-SA101C182KAR
Q2: 2SC1815; TO-92_Inline_Wide; Mouser Part 512-KSC1815YTA
R6: 47k; R_Axial_DIN0309_L9.0mm_D2.5mm_P12.70mm_Horizontal; Mouser Part 660-MF1/4LCT52R473J
R11, R12: 1k; R_Axial_DIN0309_L9.0mm_D2.5mm_P12.70mm_Horizontal; Mouser Part 660-MF1/4LCT52R102J
R28: 10k; R_Axial_DIN0309_L9.0mm_D2.5mm_P12.70mm_Horizontal; Mouser Part 660-MF1/4LCT52R103J
U5: 6581; DIP-28_W15.24mm_Socket

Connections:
1MHZ: U5.6 (ϕ2); also elsewhere on the board
+5V: C5.2, U5.25 (VCC); also elsewhere on the board
+12V: C86.2, Q2.2 (C), U5.28 (VDD); also elsewhere on the board
/Address Multiplexing/A0: U5.9 (A0); also elsewhere on the board
/Address Multiplexing/A1: U5.10 (A1); also elsewhere on the board
/Address Multiplexing/A2: U5.11 (A2); also elsewhere on the board
/Address Multiplexing/A3: U5.12 (A3); also elsewhere on the board
/Address Multiplexing/A4: U5.13 (A4); also elsewhere on the board
/CPU 8502/D0: U5.15 (D0); also elsewhere on the board
/CPU 8502/D1: U5.16 (D1); also elsewhere on the board
/CPU 8502/D2: U5.17 (D2); also elsewhere on the board
/CPU 8502/D3: U5.18 (D3); also elsewhere on the board
/CPU 8502/D4: U5.19 (D4); also elsewhere on the board
/CPU 8502/D5: U5.20 (D5); also elsewhere on the board
/CPU 8502/D6: U5.21 (D6); also elsewhere on the board
/CPU 8502/D7: U5.22 (D7); also elsewhere on the board
AUDIO_OUT: C85.2, R6.1; also elsewhere on the board
EXT_AUDIO: U5.26 (EXT_IN); also elsewhere on the board
GND: C5.1, C81.1, C84.1, C86.1, C108.1, C109.1, R6.2, R11.2, R12.2, U5.14 (GND); also elsewhere on the board
unnamed: C82.1, U5.4 (CAP2B)
unnamed: C82.2, U5.3 (CAP2A)
unnamed: C83.1, U5.2 (CAP1B)
unnamed: C83.2, U5.1 (CAP1A)
unnamed: C81.2, C112.1, Q2.3 (B), R28.1
unnamed: C84.2, C85.1, C112.2, Q2.1 (E), R12.1
unnamed: R11.1, R28.2, U5.27 (AUDIO_OUT)
POTX: C108.2, U5.24 (POTX); also elsewhere on the board
POTY: C109.2, U5.23 (POTY); also elsewhere on the board
R~W: U5.7 (R/~W); also elsewhere on the board
~CS_SID: U5.8 (~CS); also elsewhere on the board
~RESET: U5.5 (~RES); also elsewhere on the board

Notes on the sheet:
Replace +12V with UNREG +9V if 8580 is used.

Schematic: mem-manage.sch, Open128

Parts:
C2, C77: 0.01 µF; C_Disc_D10.0mm_W2.5mm_P5.00mm; Voltage Rating 25V; Voltage Tolerance +80% -20%; Mouser Part 581-SA105E103M
C3, C7, C11: 0.1 µF; C_Disc_D10.0mm_W2.5mm_P5.00mm; Voltage Rating 25V; Voltage Tolerance +80% -20%; Mouser Part 581-SA105E104MAR
J2, J3: Close to enable CAS latch; PinHeader_1x02_P2.54mm_Vertical
R33: 10k; R_Axial_DIN0309_L9.0mm_D2.5mm_P12.70mm_Horizontal; Mouser Part 660-MF1/4LCT52R103J
U3: 74LS138; DIP-16_W7.62mm; Mouser Part 595-SN74LS138N
U7: 8722; DIP-48_W15.24mm_Socket
U9: 74F32; DIP-14_W7.62mm; Mouser Part 595-SN74F32N
U11: 8721; DIP-48_W15.24mm_Socket
U31: 74LS00; DIP-14_W7.62mm; Mouser Part 595-SN74LS00N
U54: 74LS32; DIP-14_W7.62mm; Mouser Part 595-SN74LS32N
U61: 74LS08; DIP-14_W7.62mm; Mouser Part 595-SN74LS08N

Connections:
2MHZ: U7.33 (ΦIN); also elsewhere on the board
40_80: U7.48 (40/80); also elsewhere on the board
128_64: U7.47 (MS3), U11.15 (MS3); also elsewhere on the board
+5V: C2.1, C3.2, C7.1, C11.2, C77.2, R33.1, U3.6 (E3), U3.16 (VCC), U7.1 (VCC), U11.8 (DMAACK), U11.48 (VCC); also elsewhere on the board
/Address Multiplexing/A0: U7.18 (A0); also elsewhere on the board
/Address Multiplexing/A1: U7.19 (A1); also elsewhere on the board
/Address Multiplexing/A2: U7.20 (A2); also elsewhere on the board
/Address Multiplexing/A3: U7.21 (A3); also elsewhere on the board
/Address Multiplexing/A4: U54.13; also elsewhere on the board
/Address Multiplexing/A5: U54.12; also elsewhere on the board
/Address Multiplexing/A6: U54.5; also elsewhere on the board
/Address Multiplexing/A7: U54.4; also elsewhere on the board
/Address Multiplexing/A8: U3.1 (A0), U7.24 (A8); also elsewhere on the board
/Address Multiplexing/A9: U3.2 (A1), U7.25 (A9); also elsewhere on the board
/Address Multiplexing/A10: U7.26 (A10), U11.6 (A10), U31.9; also elsewhere on the board
/Address Multiplexing/A11: U3.3 (A2), U7.27 (A11), U11.5 (A11); also elsewhere on the board
/Address Multiplexing/A12: U7.28 (A12), U11.4 (A12); also elsewhere on the board
/Address Multiplexing/A13: U7.29 (A13), U11.3 (A13); also elsewhere on the board
/Address Multiplexing/A14: U7.30 (A14), U11.2 (A14); also elsewhere on the board
/Address Multiplexing/A15: U7.31 (A15), U11.1 (A15); also elsewhere on the board
/Address Multiplexing/TA8: U7.10 (TA8); also elsewhere on the board
/Address Multiplexing/TA9: U7.9 (TA9); also elsewhere on the board
/Address Multiplexing/TA10: U7.8 (TA10); also elsewhere on the board
/Address Multiplexing/TA11: U7.7 (TA11); also elsewhere on the board
/Address Multiplexing/TA12: U7.6 (TA12); also elsewhere on the board
/Address Multiplexing/TA13: U7.5 (TA13); also elsewhere on the board
/Address Multiplexing/TA14: U7.4 (TA14); also elsewhere on the board
/Address Multiplexing/TA15: U7.3 (TA15); also elsewhere on the board
/Address Multiplexing/VMA4: U11.19 (VMA4); also elsewhere on the board
/Address Multiplexing/VMA5: U11.20 (VMA5); also elsewhere on the board
/CPU 8502/D0: U7.35 (D0); also elsewhere on the board
/CPU 8502/D1: U7.36 (D1); also elsewhere on the board
/CPU 8502/D2: U7.37 (D2); also elsewhere on the board
/CPU 8502/D3: U7.38 (D3); also elsewhere on the board
/CPU 8502/D4: U7.39 (D4); also elsewhere on the board
/CPU 8502/D5: U7.40 (D5); also elsewhere on the board
/CPU 8502/D6: U7.41 (D6); also elsewhere on the board
/CPU 8502/D7: U7.42 (D7); also elsewhere on the board
/CPU 8502/P0: U11.22 (LORAM); also elsewhere on the board
/CPU 8502/P1: U11.23 (HIRAM); also elsewhere on the board
/CPU 8502/P2: U11.25 (CHAREN); also elsewhere on the board
/Memory Management/IOSEL: U7.13 (MS2), U11.16 (MS2)
/Memory Management/ROMBANKHI: U7.14 (MS1), U11.17 (MS1)
/Memory Management/ROMBANKLO: U7.15 (MS0), U11.18 (MS0)
/Memory Management/~IO_CS: U3.5 (E2), U11.38 (~I/O_CS)
AEC: U11.9 (AEC), U61.2; also elsewhere on the board
BA: U11.21 (BA); also elsewhere on the board
CLRBNK: U11.32 (CLRBNK); also elsewhere on the board
GAEC: U7.16 (AEC), U61.3; also elsewhere on the board
GND: C2.2, C3.1, C7.2, C11.1, C77.1, J2.1 (A), J3.2 (B), U3.8 (GND), U7.34 (GND), U11.24 (GND); also elsewhere on the board
MUX: U7.17 (MUX); also elsewhere on the board
unnamed: J2.2 (B), U11.7 (VICFIX)
unnamed: J3.1 (A), R33.2, U11.27 (128/256)
unnamed: U3.4 (E1), U31.8
unnamed: U7.11 (~CAS1), U9.5
unnamed: U7.12 (~CAS0), U9.2
unnamed: U9.1, U9.4, U11.41 (CASENB)
unnamed: U7.23 (A6/7), U54.6
unnamed: U7.22 (A4/5), U54.11
R~W: U7.32 (R/~W), U11.10 (R/~W); also elsewhere on the board
~CAS: U11.47 (CLK); also elsewhere on the board
~CS_8563: U3.13 (O2); also elsewhere on the board
~CS_CHAROM: U11.46 (~CHAROM); also elsewhere on the board
~CS_CIA1: U3.11 (O4); also elsewhere on the board
~CS_CIA2: U3.10 (O5); also elsewhere on the board
~CS_COLRAM: U11.45 (~COLRAM); also elsewhere on the board
~CS_FROM: U11.33 (~FROM); also elsewhere on the board
~CS_IO1: U3.9 (O6); also elsewhere on the board
~CS_IO2: U3.7 (O7); also elsewhere on the board
~CS_ROM1: U11.37 (~ROM_1); also elsewhere on the board
~CS_ROM2: U11.36 (~ROM_2); also elsewhere on the board
~CS_ROM3: U11.35 (~ROM_3); also elsewhere on the board
~CS_ROM4: U11.34 (~ROM_4); also elsewhere on the board
~CS_ROMH: U11.31 (~ROMH); also elsewhere on the board
~CS_ROML: U11.30 (~ROML); also elsewhere on the board
~CS_SID: U3.15 (O0); also elsewhere on the board
~CS_VIC: U11.42 (~VIC); also elsewhere on the board
~DMA: U61.1; also elsewhere on the board
~DWE: U11.40 (~DWE); also elsewhere on the board
~EXROM: U7.46 (~EXROM), U11.12 (~EXROM); also elsewhere on the board
~FSDIR: U7.44 (FSDIR); also elsewhere on the board
~GAME: U7.45 (~GAME), U11.11 (~GAME); also elsewhere on the board
~GCAS0: U9.3; also elsewhere on the board
~GCAS1: U9.6; also elsewhere on the board
~GWE: U11.44 (~GWE); also elsewhere on the board
~IOACC: U11.43 (~IOACC); also elsewhere on the board
~M1: U31.10; also elsewhere on the board
~MMU_Z80EN: U7.43 (~Z80EN); also elsewhere on the board
~PLA_Z80EN: U11.13 (~Z80EN); also elsewhere on the board
~RESET: U7.2 (~RESET); also elsewhere on the board
~VA14: U11.26 (~VA14); also elsewhere on the board
~Z80_IO: U11.14 (Z80_I/O); also elsewhere on the board

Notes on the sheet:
Open: 128k ROM Close: 256k ROM
Close: Enable CAS latch

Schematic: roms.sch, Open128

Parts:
C18, C32, C33, C34, C35, C36: 0.1 µF; C_Disc_D10.0mm_W2.5mm_P5.00mm; Voltage Rating 25V; Voltage Tolerance +80% -20%; Mouser Part 581-SA105E104MAR
C64: 0.01 µF; C_Disc_D10.0mm_W2.5mm_P5.00mm; Voltage Rating 25V; Voltage Tolerance +80% -20%; Mouser Part 581-SA105E103M
CN20: TA11; PinHeader_1x01_P2.54mm_Vertical
J4, J6: 128/256k; PinHeader_1x02_P2.54mm_Vertical
J7: SolderJumper_3_Bridged12; PinHeader_1x03_P2.54mm_Vertical
R36, R38: 10k; R_Axial_DIN0309_L9.0mm_D2.5mm_P12.70mm_Horizontal; Mouser Part 660-MF1/4LCT52R103J
U8: 74LS08; DIP-14_W7.62mm; Mouser Part 595-SN74LS08N
U18: 2364; DIP-24_W15.24mm_Socket
U32, U33, U34: 23128; DIP-28_W15.24mm_Socket
U35: 318020-03; DIP-28_W15.24mm_Socket
U36: 23256; DIP-28_W15.24mm_Socket

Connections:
128_64: J6.1 (A), J7.1 (A); also elsewhere on the board
+5V: C18.2, C32.2, C33.2, C34.2, C35.2, C36.2, C64.1, R36.2, R38.1, U18.24 (VCC), U32.1 (NC), U32.28 (VCC), U33.1 (NC), U33.27 (A14/CS), U33.28 (VCC), U34.1 (NC), U34.28 (VCC), U35.1 (NC), U35.27 (A14/CS), U35.28 (VCC), U36.1 (NC), U36.28 (VCC); also elsewhere on the board
/Address Multiplexing/A0: U32.10 (A0), U33.10 (A0), U34.10 (A0), U35.10 (A0), U36.10 (A0); also elsewhere on the board
/Address Multiplexing/A1: U32.9 (A1), U33.9 (A1), U34.9 (A1), U35.9 (A1), U36.9 (A1); also elsewhere on the board
/Address Multiplexing/A2: U32.8 (A2), U33.8 (A2), U34.8 (A2), U35.8 (A2), U36.8 (A2); also elsewhere on the board
/Address Multiplexing/A3: U32.7 (A3), U33.7 (A3), U34.7 (A3), U35.7 (A3), U36.7 (A3); also elsewhere on the board
/Address Multiplexing/A4: U32.6 (A4), U33.6 (A4), U34.6 (A4), U35.6 (A4), U36.6 (A4); also elsewhere on the board
/Address Multiplexing/A5: U32.5 (A5), U33.5 (A5), U34.5 (A5), U35.5 (A5), U36.5 (A5); also elsewhere on the board
/Address Multiplexing/A6: U32.4 (A6), U33.4 (A6), U34.4 (A6), U35.4 (A6), U36.4 (A6); also elsewhere on the board
/Address Multiplexing/A7: U32.3 (A7), U33.3 (A7), U34.3 (A7), U35.3 (A7), U36.3 (A7); also elsewhere on the board
/Address Multiplexing/A8: U32.25 (A8), U33.25 (A8), U34.25 (A8), U35.25 (A8), U36.25 (A8); also elsewhere on the board
/Address Multiplexing/A9: U32.24 (A9), U33.24 (A9), U34.24 (A9), U35.24 (A9), U36.24 (A9); also elsewhere on the board
/Address Multiplexing/A10: U32.21 (A10), U33.21 (A10), U34.21 (A10), U35.21 (A10), U36.21 (A10); also elsewhere on the board
/Address Multiplexing/A11: U32.23 (A11), U33.23 (A11), U34.23 (A11), U35.23 (A11), U36.23 (A11); also elsewhere on the board
/Address Multiplexing/A12: U33.2 (A12), U34.2 (A12), U36.2 (A12); also elsewhere on the board
/Address Multiplexing/A13: U8.12, U33.26 (A13), U34.26 (A13), U35.26 (A13), U36.26 (A13); also elsewhere on the board
/Address Multiplexing/A14: U36.27 (A14/CS); also elsewhere on the board
/Address Multiplexing/A15: J4.1 (A); also elsewhere on the board
/Address Multiplexing/SA0: U18.8 (A0); also elsewhere on the board
/Address Multiplexing/SA1: U18.7 (A1); also elsewhere on the board
/Address Multiplexing/SA2: U18.6 (A2); also elsewhere on the board
/Address Multiplexing/SA3: U18.5 (A3); also elsewhere on the board
/Address Multiplexing/SA4: U18.4 (A4); also elsewhere on the board
/Address Multiplexing/SA5: U18.3 (A5); also elsewhere on the board
/Address Multiplexing/SA6: U18.2 (A6); also elsewhere on the board
/Address Multiplexing/SA7: U18.1 (A7); also elsewhere on the board
/Address Multiplexing/TA8: U18.23 (A8); also elsewhere on the board
/Address Multiplexing/TA9: U18.22 (A9); also elsewhere on the board
/Address Multiplexing/TA10: U18.19 (A10); also elsewhere on the board
/Address Multiplexing/TA11: CN20.1, U18.18 (A11); also elsewhere on the board
/Address Multiplexing/TA12: U32.2 (A12), U35.2 (A12); also elsewhere on the board
/Address Multiplexing/TA14: U8.13; also elsewhere on the board
/CPU 8502/D0: U18.9 (D0), U32.11 (D0), U33.11 (D0), U34.11 (D0), U35.11 (D0), U36.11 (D0); also elsewhere on the board
/CPU 8502/D1: U18.10 (D1), U32.12 (D1), U33.12 (D1), U34.12 (D1), U35.12 (D1), U36.12 (D1); also elsewhere on the board
/CPU 8502/D2: U18.11 (D2), U32.13 (D2), U33.13 (D2), U34.13 (D2), U35.13 (D2), U36.13 (D2); also elsewhere on the board
/CPU 8502/D3: U18.13 (D3), U32.15 (D3), U33.15 (D3), U34.15 (D3), U35.15 (D3), U36.15 (D3); also elsewhere on the board
/CPU 8502/D4: U18.14 (D4), U32.16 (D4), U33.16 (D4), U34.16 (D4), U35.16 (D4), U36.16 (D4); also elsewhere on the board
/CPU 8502/D5: U18.15 (D5), U32.17 (D5), U33.17 (D5), U34.17 (D5), U35.17 (D5), U36.17 (D5); also elsewhere on the board
/CPU 8502/D6: U18.16 (D6), U32.18 (D6), U33.18 (D6), U34.18 (D6), U35.18 (D6), U36.18 (D6); also elsewhere on the board
/CPU 8502/D7: U18.17 (D7), U32.19 (D7), U33.19 (D7), U34.19 (D7), U35.19 (D7), U36.19 (D7); also elsewhere on the board
CAPSLK: J7.3 (B); also elsewhere on the board
GND: C18.1, C32.1, C33.1, C34.1, C35.1, C36.1, C64.2, U18.12 (GND), U32.14 (GND), U32.20 (~CE), U33.14 (GND), U33.20 (~CE), U34.14 (GND), U34.20 (~CE), U35.14 (GND), U35.20 (~CE), U36.14 (GND), U36.20 (~CE); also elsewhere on the board
unnamed: J4.2 (B), R36.1, U34.27 (A14/CS)
unnamed: J6.2 (B), R38.2, U32.27 (A14/CS)
unnamed: J7.2 (C), U18.21 (A12)
unnamed: U8.11, U32.26 (A13)
~CS_CHAROM: U18.20 (CS/~CS); also elsewhere on the board
~CS_FROM: U36.22 (~OE); also elsewhere on the board
~CS_ROM1: U32.22 (~OE); also elsewhere on the board
~CS_ROM2: U33.22 (~OE); also elsewhere on the board
~CS_ROM3: U34.22 (~OE); also elsewhere on the board
~CS_ROM4: U35.22 (~OE); also elsewhere on the board

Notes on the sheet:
C64 ROM BASIC / KERNAL
CHARACTER ROM
BASIC ROM LO [4000 - 7FFFF]
BASIC ROM HI [8000 - BFFFF]
KERNAL ROM [C000 - FFFF]
FUNCTION ROM Empty socket

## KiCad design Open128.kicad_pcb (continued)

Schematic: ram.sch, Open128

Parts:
C38, C39, C40, C41, C42, C43, C44, C45, C46, C47, C48, C49, C50, C51, C52, C53: 0.22 µF; C_Disc_D10.0mm_W2.5mm_P5.00mm; Voltage Rating 25V; Voltage Tolerance +80% -20%; Mouser Part 581-SA105E104MAR
C65, C67: 0.01 µF; C_Disc_D10.0mm_W2.5mm_P5.00mm; Voltage Rating 25V; Voltage Tolerance +80% -20%; Mouser Part 581-SA105E103M
C66: 0.01 µF; C_Axial_L5.1mm_D3.1mm_P12.50mm_Horizontal; Mouser Part 581-SA105E103M
R1, R29, R30: 68; R_Axial_DIN0309_L9.0mm_D2.5mm_P12.70mm_Horizontal; Mouser Part 660-MF1/4DCT52R68R0F
RP6: 1k; R_Array_SIP9; Mouser Part 652-4609X-1LF-1K
U9: 74F32; DIP-14_W7.62mm; Mouser Part 595-SN74F32N
U38, U39, U40, U41, U42, U43, U44, U45, U46, U47, U48, U49, U50, U51, U52, U53: 4164; DIP-16_W7.62mm_Socket

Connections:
+5V: C38.1, C39.1, C40.1, C41.1, C42.1, C43.1, C44.1, C45.1, C46.1, C47.1, C48.1, C49.1, C50.1, C51.1, C52.1, C53.1, C65.1, C66.1, C67.1, RP6.1 (common), U38.8 (VDD), U39.8 (VDD), U40.8 (VDD), U41.8 (VDD), U42.8 (VDD), U43.8 (VDD), U44.8 (VDD), U45.8 (VDD), U46.8 (VDD), U47.8 (VDD), U48.8 (VDD), U49.8 (VDD), U50.8 (VDD), U51.8 (VDD), U52.8 (VDD), U53.8 (VDD); also elsewhere on the board
/Address Multiplexing/MA0: RP6.8 (R7), U38.5 (A0), U39.5 (A0), U40.5 (A0), U41.5 (A0), U42.5 (A0), U43.5 (A0), U44.5 (A0), U45.5 (A0), U46.5 (A0), U47.5 (A0), U48.5 (A0), U49.5 (A0), U50.5 (A0), U51.5 (A0), U52.5 (A0), U53.5 (A0); also elsewhere on the board
/Address Multiplexing/MA1: RP6.2 (R1), U38.7 (A1), U39.7 (A1), U40.7 (A1), U41.7 (A1), U42.7 (A1), U43.7 (A1), U44.7 (A1), U45.7 (A1), U46.7 (A1), U47.7 (A1), U48.7 (A1), U49.7 (A1), U50.7 (A1), U51.7 (A1), U52.7 (A1), U53.7 (A1); also elsewhere on the board
/Address Multiplexing/MA2: RP6.6 (R5), U38.6 (A2), U39.6 (A2), U40.6 (A2), U41.6 (A2), U42.6 (A2), U43.6 (A2), U44.6 (A2), U45.6 (A2), U46.6 (A2), U47.6 (A2), U48.6 (A2), U49.6 (A2), U50.6 (A2), U51.6 (A2), U52.6 (A2), U53.6 (A2); also elsewhere on the board
/Address Multiplexing/MA3: RP6.7 (R6), U38.12 (A3), U39.12 (A3), U40.12 (A3), U41.12 (A3), U42.12 (A3), U43.12 (A3), U44.12 (A3), U45.12 (A3), U46.12 (A3), U47.12 (A3), U48.12 (A3), U49.12 (A3), U50.12 (A3), U51.12 (A3), U52.12 (A3), U53.12 (A3); also elsewhere on the board
/Address Multiplexing/MA4: RP6.5 (R4), U38.11 (A4), U39.11 (A4), U40.11 (A4), U41.11 (A4), U42.11 (A4), U43.11 (A4), U44.11 (A4), U45.11 (A4), U46.11 (A4), U47.11 (A4), U48.11 (A4), U49.11 (A4), U50.11 (A4), U51.11 (A4), U52.11 (A4), U53.11 (A4); also elsewhere on the board
/Address Multiplexing/MA5: RP6.4 (R3), U38.10 (A5), U39.10 (A5), U40.10 (A5), U41.10 (A5), U42.10 (A5), U43.10 (A5), U44.10 (A5), U45.10 (A5), U46.10 (A5), U47.10 (A5), U48.10 (A5), U49.10 (A5), U50.10 (A5), U51.10 (A5), U52.10 (A5), U53.10 (A5); also elsewhere on the board
/Address Multiplexing/MA6: RP6.9 (R8), U38.13 (A6), U39.13 (A6), U40.13 (A6), U41.13 (A6), U42.13 (A6), U43.13 (A6), U44.13 (A6), U45.13 (A6), U46.13 (A6), U47.13 (A6), U48.13 (A6), U49.13 (A6), U50.13 (A6), U51.13 (A6), U52.13 (A6), U53.13 (A6); also elsewhere on the board
/Address Multiplexing/MA7: RP6.3 (R2), U38.9 (A7), U39.9 (A7), U40.9 (A7), U41.9 (A7), U42.9 (A7), U43.9 (A7), U44.9 (A7), U45.9 (A7), U46.9 (A7), U47.9 (A7), U48.9 (A7), U49.9 (A7), U50.9 (A7), U51.9 (A7), U52.9 (A7), U53.9 (A7); also elsewhere on the board
/CPU 8502/D0: U38.2 (D), U38.14 (Q), U46.2 (D), U46.14 (Q); also elsewhere on the board
/CPU 8502/D1: U39.2 (D), U39.14 (Q), U47.2 (D), U47.14 (Q); also elsewhere on the board
/CPU 8502/D2: U40.2 (D), U40.14 (Q), U48.2 (D), U48.14 (Q); also elsewhere on the board
/CPU 8502/D3: U41.2 (D), U41.14 (Q), U49.2 (D), U49.14 (Q); also elsewhere on the board
/CPU 8502/D4: U42.2 (D), U42.14 (Q), U50.2 (D), U50.14 (Q); also elsewhere on the board
/CPU 8502/D5: U43.2 (D), U43.14 (Q), U51.2 (D), U51.14 (Q); also elsewhere on the board
/CPU 8502/D6: U44.2 (D), U44.14 (Q), U52.2 (D), U52.14 (Q); also elsewhere on the board
/CPU 8502/D7: U45.2 (D), U45.14 (Q), U53.2 (D), U53.14 (Q); also elsewhere on the board
GND: C38.2, C39.2, C40.2, C41.2, C42.2, C43.2, C44.2, C45.2, C46.2, C47.2, C48.2, C49.2, C50.2, C51.2, C52.2, C53.2, C65.2, C66.2, C67.2, U38.16 (VSS), U39.16 (VSS), U40.16 (VSS), U41.16 (VSS), U42.16 (VSS), U43.16 (VSS), U44.16 (VSS), U45.16 (VSS), U46.16 (VSS), U47.16 (VSS), U48.16 (VSS), U49.16 (VSS), U50.16 (VSS), U51.16 (VSS), U52.16 (VSS), U53.16 (VSS); also elsewhere on the board
unnamed: R1.1, U38.4 (~RAS), U39.4 (~RAS), U40.4 (~RAS), U41.4 (~RAS), U42.4 (~RAS), U43.4 (~RAS), U44.4 (~RAS), U45.4 (~RAS), U46.4 (~RAS), U47.4 (~RAS), U48.4 (~RAS), U49.4 (~RAS), U50.4 (~RAS), U51.4 (~RAS), U52.4 (~RAS), U53.4 (~RAS)
unnamed: R29.1, U38.15 (~CAS), U39.15 (~CAS), U40.15 (~CAS), U41.15 (~CAS), U42.15 (~CAS), U43.15 (~CAS), U44.15 (~CAS), U45.15 (~CAS)
unnamed: R29.2, U9.8
unnamed: R30.1, U46.15 (~CAS), U47.15 (~CAS), U48.15 (~CAS), U49.15 (~CAS), U50.15 (~CAS), U51.15 (~CAS), U52.15 (~CAS), U53.15 (~CAS)
unnamed: R30.2, U9.11
~CAS: U9.10, U9.12; also elsewhere on the board
~DWE: U38.3 (~W), U39.3 (~W), U40.3 (~W), U41.3 (~W), U42.3 (~W), U43.3 (~W), U44.3 (~W), U45.3 (~W), U46.3 (~W), U47.3 (~W), U48.3 (~W), U49.3 (~W), U50.3 (~W), U51.3 (~W), U52.3 (~W), U53.3 (~W); also elsewhere on the board
~GCAS0: U9.9; also elsewhere on the board
~GCAS1: U9.13; also elsewhere on the board
~RAS: R1.2; also elsewhere on the board

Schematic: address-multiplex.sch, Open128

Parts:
C14, C15, C17, C26, C55: 0.1 µF; C_Disc_D10.0mm_W2.5mm_P5.00mm; Voltage Rating 25V; Voltage Tolerance +80% -20%; Mouser Part 581-SA105E104MAR
C121: 0.01 µF; C_Disc_D10.0mm_W2.5mm_P5.00mm; Voltage Rating 25V; Voltage Tolerance +80% -20%; Mouser Part 581-SA105E104MAR
RP3, RP4: 33; R_Array_SIP8; Mouser Part 652-4608X-2LF-33
RP8: 3.3k; R_Array_SIP10; Mouser Part 652-4610X-1LF-3.3K
RP9, RP10: 10k; R_Array_SIP10; Mouser Part 652-4610X-1LF-10K
U14, U15, U26: 74LS257; DIP-16_W7.62mm; Mouser Part 595-SN74LS257BN
U17: 74LS373; DIP-20_W7.62mm; Mouser Part 595-SN74LS373N
U55: 74LS245; DIP-20_W7.62mm; Mouser Part 595-SN74LS245N
U62: 74LS244; DIP-20_W7.62mm; Mouser Part 595-SN74LS244N

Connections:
+5V: C14.2, C15.2, C17.2, C26.2, C55.2, C121.2, RP8.1 (common), RP9.1 (common), RP10.1 (common), U14.16 (VCC), U15.16 (VCC), U17.20 (VCC), U26.16 (VCC), U55.20 (VCC), U62.20 (VCC); also elsewhere on the board
/Address Multiplexing/A0: RP9.10 (R9), U15.13 (I1c), U55.3 (A1); also elsewhere on the board
/Address Multiplexing/A1: RP9.9 (R8), U15.10 (I1d), U55.5 (A3); also elsewhere on the board
/Address Multiplexing/A2: RP9.8 (R7), U15.6 (I1b), U55.7 (A5); also elsewhere on the board
/Address Multiplexing/A3: RP9.7 (R6), U15.3 (I1a), U55.9 (A7); also elsewhere on the board
/Address Multiplexing/A4: RP9.6 (R5), U14.13 (I1c), U55.8 (A6); also elsewhere on the board
/Address Multiplexing/A5: RP9.5 (R4), U14.10 (I1d), U55.6 (A4); also elsewhere on the board
/Address Multiplexing/A6: RP9.4 (R3), U14.6 (I1b), U55.4 (A2); also elsewhere on the board
/Address Multiplexing/A7: RP9.3 (R2), U14.3 (I1a), U55.2 (A0); also elsewhere on the board
/Address Multiplexing/A8: RP10.2 (R1), U62.9 (O0b); also elsewhere on the board
/Address Multiplexing/A9: RP10.3 (R2), U62.12 (O3a); also elsewhere on the board
/Address Multiplexing/A10: RP10.4 (R3), U62.7 (O1b); also elsewhere on the board
/Address Multiplexing/A11: RP10.5 (R4), U62.14 (O2a); also elsewhere on the board
/Address Multiplexing/A12: RP10.6 (R5), U62.5 (O2b); also elsewhere on the board
/Address Multiplexing/A13: RP10.7 (R6), U62.16 (O1a); also elsewhere on the board
/Address Multiplexing/A14: RP10.8 (R7), U62.3 (O3b); also elsewhere on the board
/Address Multiplexing/A15: RP10.9 (R8), U62.18 (O0a); also elsewhere on the board
/Address Multiplexing/MA0: RP4.4 (R2); also elsewhere on the board
/Address Multiplexing/MA1: RP4.8 (R4); also elsewhere on the board
/Address Multiplexing/MA2: RP4.6 (R3); also elsewhere on the board
/Address Multiplexing/MA3: RP4.2 (R1); also elsewhere on the board
/Address Multiplexing/MA4: RP3.6 (R3); also elsewhere on the board
/Address Multiplexing/MA5: RP3.8 (R4); also elsewhere on the board
/Address Multiplexing/MA6: RP3.4 (R2); also elsewhere on the board
/Address Multiplexing/MA7: RP3.2 (R1); also elsewhere on the board
/Address Multiplexing/SA0: U17.2 (O0), U55.17 (B1); also elsewhere on the board
/Address Multiplexing/SA1: U17.5 (O1), U55.15 (B3); also elsewhere on the board
/Address Multiplexing/SA2: U17.6 (O2), U55.13 (B5); also elsewhere on the board
/Address Multiplexing/SA3: U17.9 (O3), U55.11 (B7); also elsewhere on the board
/Address Multiplexing/SA4: U17.12 (O4), U55.12 (B6); also elsewhere on the board
/Address Multiplexing/SA5: U17.15 (O5), U55.14 (B4); also elsewhere on the board
/Address Multiplexing/SA6: U17.16 (O6), U55.16 (B2); also elsewhere on the board
/Address Multiplexing/SA7: U17.19 (O7), U55.18 (B0); also elsewhere on the board
/Address Multiplexing/TA8: U15.14 (I0c), U62.11 (I0b); also elsewhere on the board
/Address Multiplexing/TA9: U15.11 (I0d), U62.8 (I3a); also elsewhere on the board
/Address Multiplexing/TA10: U15.5 (I0b), U62.13 (I1b); also elsewhere on the board
/Address Multiplexing/TA11: U15.2 (I0a), U62.6 (I2a); also elsewhere on the board
/Address Multiplexing/TA12: RP8.5 (R4), U14.14 (I0c), U62.15 (I2b); also elsewhere on the board
/Address Multiplexing/TA13: RP8.4 (R3), U14.11 (I0d), U62.4 (I1a); also elsewhere on the board
/Address Multiplexing/TA14: RP8.3 (R2), U14.5 (I0b), U62.17 (I3b); also elsewhere on the board
/Address Multiplexing/TA15: RP8.2 (R1), U14.2 (I0a), U62.2 (I0a); also elsewhere on the board
/Address Multiplexing/VMA0: RP4.3 (R2), U15.12 (Zc), U17.3 (D0); also elsewhere on the board
/Address Multiplexing/VMA1: RP4.7 (R4), U15.9 (Zd), U17.4 (D1); also elsewhere on the board
/Address Multiplexing/VMA2: RP4.5 (R3), U15.7 (Zb), U17.7 (D2); also elsewhere on the board
/Address Multiplexing/VMA3: RP4.1 (R1), U15.4 (Za), U17.8 (D3); also elsewhere on the board
/Address Multiplexing/VMA4: RP3.5 (R3), U14.12 (Zc), U17.13 (D4); also elsewhere on the board
/Address Multiplexing/VMA5: RP3.7 (R4), U14.9 (Zd), U17.14 (D5); also elsewhere on the board
/Address Multiplexing/VMA6: RP3.3 (R2), U14.7 (Zb), U26.4 (Za)
/Address Multiplexing/VMA7: RP3.1 (R1), U14.4 (Za), U26.7 (Zb)
AEC: U17.1 (OE), U26.15 (OE); also elsewhere on the board
GND: C14.1, C15.1, C17.1, C26.1, C55.1, C121.1, U14.8 (GND), U15.8 (GND), U17.10 (GND), U26.8 (GND), U26.10 (I1d), U26.11 (I0d), U26.14 (I0c), U55.10 (GND), U62.10 (GND); also elsewhere on the board
MUX: U14.1 (S), U15.1 (S), U26.1 (S); also elsewhere on the board
unnamed: U17.11 (LE), U26.12 (Zc)
VA6: U17.17 (D6), U26.3 (I1a); also elsewhere on the board
VA7: U17.18 (D7), U26.6 (I1b); also elsewhere on the board
VA14: U26.2 (I0a); also elsewhere on the board
VA15: U26.5 (I0b); also elsewhere on the board
~AEC: U14.15 (OE), U15.15 (OE), U55.19 (CE); also elsewhere on the board
~DMA: U55.1 (A->B), U62.1 (OEa), U62.19 (OEb); also elsewhere on the board
~RAS: U26.13 (I1c); also elsewhere on the board

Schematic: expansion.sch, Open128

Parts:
CN1: Expansion bus; EXPANSIONPORT
R43: 3.3k; R_Axial_DIN0309_L9.0mm_D2.5mm_P12.70mm_Horizontal; Mouser Part 660-MF1/4LCT52R332J
RP5: 3.3k; R_Array_SIP8; Mouser Part 652-4608X-1LF-3.3K

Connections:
1MHZ: CN1.E; also elsewhere on the board
+5V: CN1.2, CN1.3, R43.1, RP5.1 (common); also elsewhere on the board
/Address Multiplexing/SA0: CN1.Y; also elsewhere on the board
/Address Multiplexing/SA1: CN1.X; also elsewhere on the board
/Address Multiplexing/SA2: CN1.W; also elsewhere on the board
/Address Multiplexing/SA3: CN1.V; also elsewhere on the board
/Address Multiplexing/SA4: CN1.U; also elsewhere on the board
/Address Multiplexing/SA5: CN1.T; also elsewhere on the board
/Address Multiplexing/SA6: CN1.S; also elsewhere on the board
/Address Multiplexing/SA7: CN1.R; also elsewhere on the board
/Address Multiplexing/TA8: CN1.P; also elsewhere on the board
/Address Multiplexing/TA9: CN1.N; also elsewhere on the board
/Address Multiplexing/TA10: CN1.M; also elsewhere on the board
/Address Multiplexing/TA11: CN1.L; also elsewhere on the board
/Address Multiplexing/TA12: CN1.K; also elsewhere on the board
/Address Multiplexing/TA13: CN1.J; also elsewhere on the board
/Address Multiplexing/TA14: CN1.H; also elsewhere on the board
/Address Multiplexing/TA15: CN1.F; also elsewhere on the board
/CPU 8502/D0: CN1.21; also elsewhere on the board
/CPU 8502/D1: CN1.20; also elsewhere on the board
/CPU 8502/D2: CN1.19; also elsewhere on the board
/CPU 8502/D3: CN1.18; also elsewhere on the board
/CPU 8502/D4: CN1.17; also elsewhere on the board
/CPU 8502/D5: CN1.16; also elsewhere on the board
/CPU 8502/D6: CN1.15; also elsewhere on the board
/CPU 8502/D7: CN1.14; also elsewhere on the board
BA: CN1.12; also elsewhere on the board
GND: CN1.1, CN1.22, CN1.A, CN1.Z; also elsewhere on the board
R~W: CN1.5; also elsewhere on the board
~CS_IO1: CN1.7; also elsewhere on the board
~CS_IO2: CN1.10; also elsewhere on the board
~CS_ROMH: CN1.B; also elsewhere on the board
~CS_ROML: CN1.11; also elsewhere on the board
~DMA: CN1.13, R43.2; also elsewhere on the board
~EXROM: CN1.9, RP5.8 (R7); also elsewhere on the board
~GAME: CN1.8, RP5.7 (R6); also elsewhere on the board
~IRQ: CN1.4; also elsewhere on the board
~NMI: CN1.D; also elsewhere on the board
~RESET: CN1.C; also elsewhere on the board
~ΦDOT: CN1.6; also elsewhere on the board

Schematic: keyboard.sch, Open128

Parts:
C89: 51 pF; C_Disc_D10.0mm_W2.5mm_P5.00mm; Mouser Part 581-SA102A510JAA
C90: 360 pF; C_Disc_D10.0mm_W2.5mm_P5.00mm
C114: 0.01 µF; C_Disc_D10.0mm_W2.5mm_P5.00mm; Voltage Rating 25V; Voltage Tolerance +80% -20%; Mouser Part 581-SA105E103M
CN5: Conn_01x25; DSUB-25_Female_Horizontal_P2.77x2.84mm_EdgePinOffset7.70mm_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
R9, R20: 10k; R_Axial_DIN0309_L9.0mm_D2.5mm_P12.70mm_Horizontal; Mouser Part 660-MF1/4LCT52R103J
R21: 470k; R_Axial_DIN0309_L9.0mm_D2.5mm_P12.70mm_Horizontal; Mouser Part 660-MF1/4LCT52R474J
R22: 47k; R_Axial_DIN0309_L9.0mm_D2.5mm_P12.70mm_Horizontal; Mouser Part 660-MF1/4LCT52R473J
RP2: 1k; R_Array_SIP9; Mouser Part 652-4609X-1LF-1K
RP8: 3.3k; R_Array_SIP10; Mouser Part 652-4610X-1LF-3.3K
U16: 74LS14; DIP-14_W7.62mm; Mouser Part 595-SN74LS14N
U27: LM556; DIP-14_W7.62mm; Mouser Part 595-NA556N
U29, U37: 7406; DIP-14_W7.62mm; Mouser Part 595-SN74LS06N
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

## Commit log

2021-03-22 Add notice about board not tested yet
2021-03-22 Add PDF schematic and gerber files
    [Open128-B_Cu.gbr, Open128-B_Mask.gbr, Open128-B_SilkS.gbr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]
2021-06-22 Fix R47/R101
    [Open128-B_Cu.gbr, Open128-B_Mask.gbr, Open128-B_SilkS.gbr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]
2021-09-17 Clean up schematic
    [IO.sch, Open128.kicad_pcb, Open128.sch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]
2021-09-17 Updated PDF to matched cleaned schematic
